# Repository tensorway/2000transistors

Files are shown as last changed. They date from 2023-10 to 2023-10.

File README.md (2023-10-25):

# 2000 MOSFET processor

The project is made in Kicad. If you want to learn more about it visit [howcpuworks.com](howcpuworks.com).

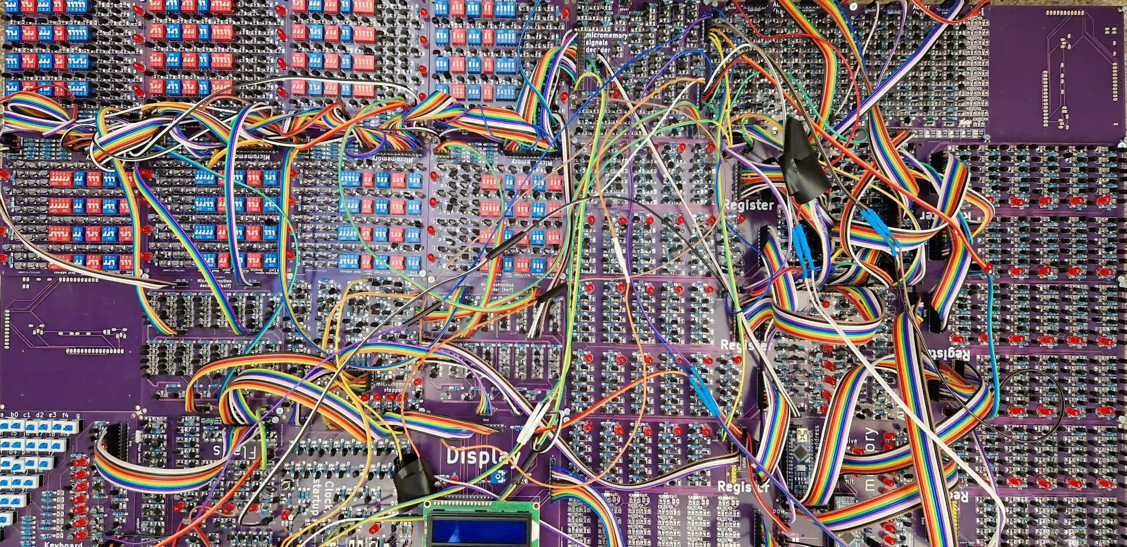
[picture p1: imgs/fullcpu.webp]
Full cpu AnVIL Portal Image!

Hello world AnVIL Portal Image!

## Conventions
- all transistors on a board point into the same direction (or 2 perpendicular ones if needed)
- all leds point into the same direction
- 1k resistors are labeled with white rectangle, 1M with empty one (only violation is in the Clock board and two voltage divider resistors in LCD board)
- "*" means high significance bits
- "+" means positive 5V

## Tips
- you dont need to use extra usb for the power, powering through arduino is enough
- Adder is made out of 2 smaller 6 bit adders, this means that you do not have to solder one bit (6+6=12 != 11)
- instruction register needs only 5bits which means you do not have to solder upper 6 bits (all registers are the same board to lower costs)
- when soldering
  - first put resistors
  - than transistors from the top left (top right if left handed)
  - leds and pin headers last

## Important
- to lower costs all registers have the same board, but TMP and IR registers do not have input and output connected to the bus, this means you have to connect it on other registers
- You need to find the voltage that works for your LCD contrast and put those resistors

## Components
- 2N7000 MOSFETs
- BC547 (BJT) only 4 for the astable
- 1000 ohm registers for leds
- 1M ohm for logic

## Bugs

While I could fix the bugs I do not want to check is everything working again because I would need to solder things again. This is why I list them, so you can either fix them yourselves before or after soldering (I did after).
Some bugs are just layout bugs, which means you need to be aware of them but not necessarily fix them.

Micromemory:
- shuffled by row led, select and switches - layout bug
- 0th line not connected to rest

Micromemory stepper:
- shuffeled LED state order - layout bug
- add delay from clock to it (for example RC)
   
Keyboard
- same signals for simetrical (with respect to keyboard diagonal) switches
  - effectively half the number of switches
- 1 bit not connected
  
Flags
- second to last carry and last carry labels mixed - layout bug
- flags selector selects 0 always

Clock
- manual clock does not have a debouncer

ALU
- add OR between ALU decoded ops and give Adder the output

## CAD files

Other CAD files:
src/kicad-footprints-master/Sources/Inductor_SMD/L_Coilcraft_LPS5030.FCStd
src/kicad-footprints-master/Sources/Package_LGA/Infineon_PG-LLGA-5-1.FCStd
src/kicad-footprints-master/Sources/Package_SON/X2SON-4_1x1mm_P0.65mm.fcstd
src/kicad-footprints-master/Sources/Package_TO_SOT_THT/sod-70.fcstd
src/kicad-footprints-master/Sources/Inductor_SMD/L_Wuerth_WE-TPC-3816.FCStd
src/kicad-footprints-master/Sources/Package_SON/X2SON-5_0.8x0.8mm_P0.48mm.fcstd
src/kicad-footprints-master/Sources/Package_TO_SOT_THT/sod-70_P5.08mm.fcstd

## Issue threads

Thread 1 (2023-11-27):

quick question

Dumnersm580, 2023-11-27:
what pcb's do i need to start this build?

Dumnersm580, 2023-11-27:
If possible could you provide a good photo of the adder? and i am guessing the ressistors needed for this board are the 1 mega ohm

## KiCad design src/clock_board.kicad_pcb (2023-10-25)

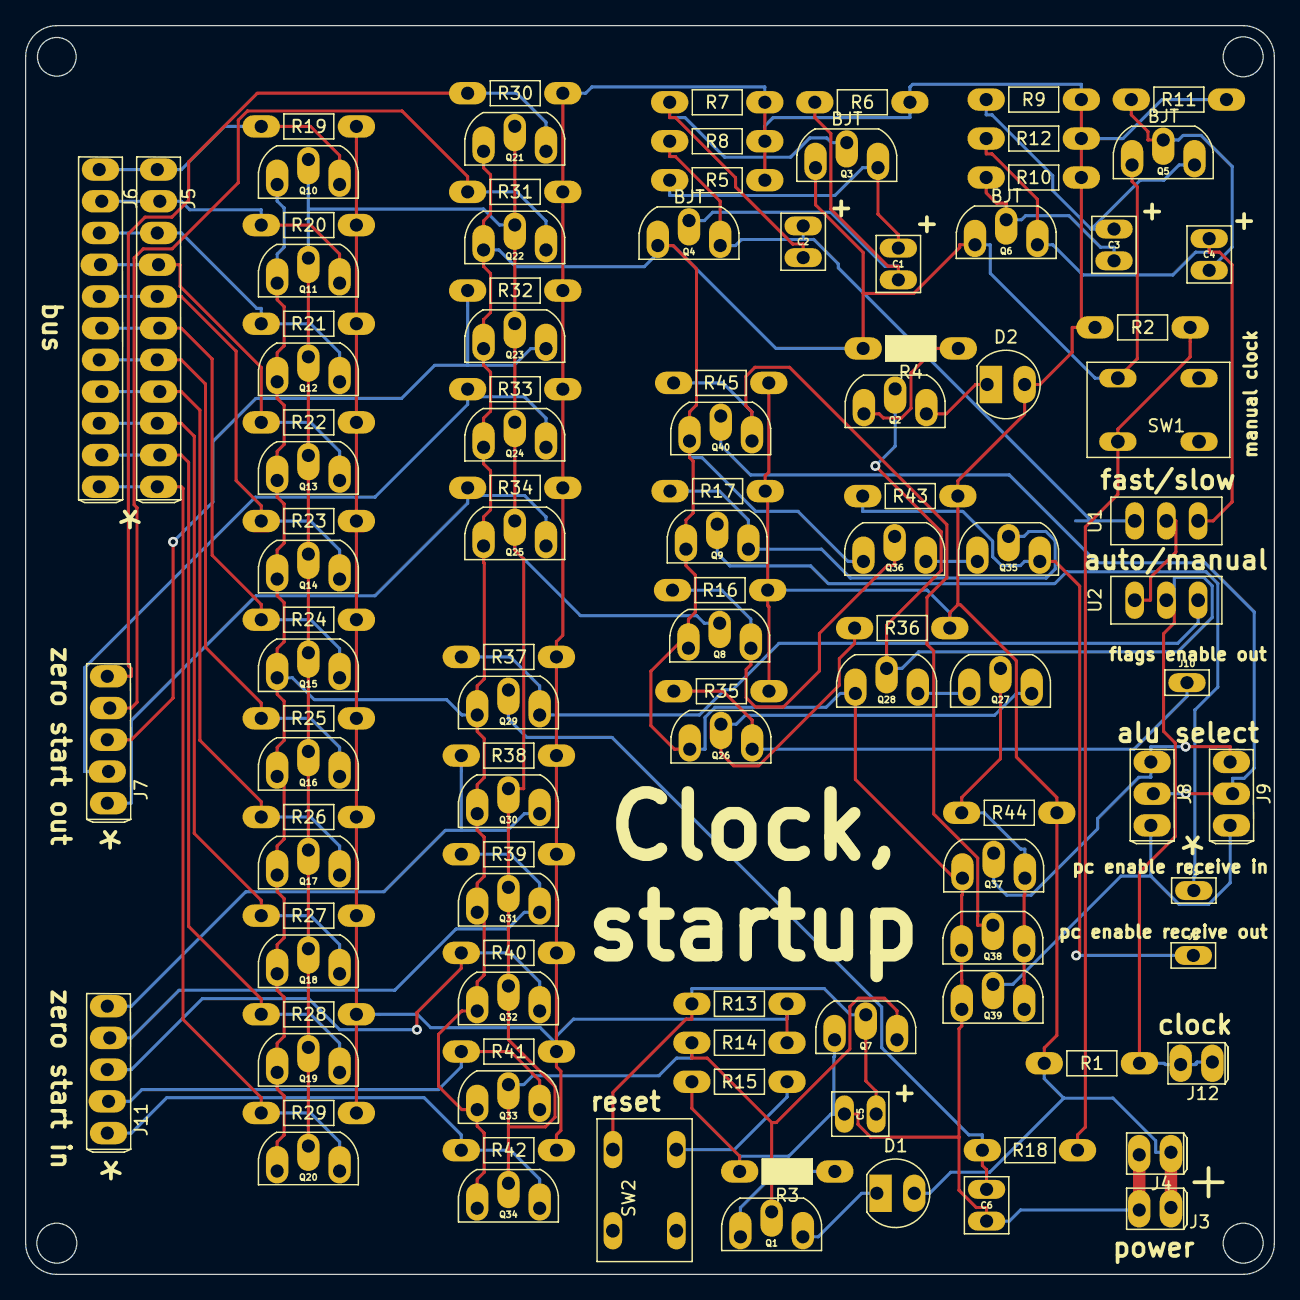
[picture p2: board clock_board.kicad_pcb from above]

Board: 2 copper layers, 100.0 x 100.0 mm, 109 parts (0 on the bottom side), 56 nets.

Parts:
C1, C2, C3, C4: CP; capacitor
C5, C6: C; capacitor
D1, D2: LED; led_5mm_tight
J1, J2: Conn_01x01_Male; 1pin
J3, J4, J12: Conn_01x02_Male; 2pin_tight
J5, J6: Conn_01x11_Male; 11pin_tight
J7, J11: Conn_01x05_Male; 5pin_tight
J8, J9: alu_sel; 3pin_tight
J10: flags_enable_out; 1pin
Q1, Q2, Q7, Q8, Q9, Q10, Q11, Q12, Q13, Q14, Q15, Q16, Q17, Q18, Q19, Q20, Q21, Q22, Q23, Q24, Q25, Q26, Q27, Q28, Q29, Q30, Q31, Q32, Q33, Q34, Q35, Q36, Q37, Q38, Q39, Q40: 2N7000; 2n7000_tight
Q3, Q4, Q5, Q6: 2N2219; bjt
R1, R2, R5, R6, R7, R8, R9, R10, R11, R12, R13, R14, R15, R16, R17, R18, R19, R20, R21, R22, R23, R24, R25, R26, R27, R28, R29, R30, R31, R32, R33, R34, R35, R36, R37, R38, R39, R40, R41, R42, R43, R44, R45: R; resistor_tight
R3, R4: R; resistor_led_tight
SW1, SW2: SW_Push_Dual; push_button
U1, U2: slide_switch

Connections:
+5V: D1.2, D2.2, J3.1, J4.1, R1.1, R2.1, R5.1, R6.1, R7.1, R8.1, R9.1, R10.1, R11.1, R12.1, R13.1, R14.1, R16.1, R17.1, R19.1, R20.1, R21.1, R22.1, R23.1, R24.1, R25.1, R26.1, R27.1, R28.1, R29.1, R30.1, R31.1, R32.1, R33.1, R34.1, R35.1, R36.1, R37.1, R38.1, R39.1, R40.1, R41.1, R42.1, R43.1, R44.1, R45.1
/Sheet63E28E4F/a: J5.11, J6.11, Q20.3, R29.2
/Sheet63E28E4F/ain: Q1.2, Q7.3, Q8.2, Q10.2, Q11.2, Q12.2, Q13.2, Q14.2, Q15.2, Q16.2, Q17.2, Q18.2, Q19.2, Q20.2, Q21.2, Q22.2, Q23.2, Q24.2, Q25.2, Q30.2, Q31.2, Q32.2, Q33.2, Q34.2, R14.2
/Sheet63E28E4F/b: J5.10, J6.10, Q19.3, R28.2
/Sheet63E28E4F/c: J5.9, J6.9, Q18.3, R27.2
/Sheet63E28E4F/d: J5.8, J6.8, Q17.3, R26.2
/Sheet63E28E4F/e: J5.7, J6.7, Q16.3, R25.2
/Sheet63E28E4F/f: J5.6, J6.6, Q15.3, R24.2
/Sheet63E28E4F/g: J5.5, J6.5, Q14.3, R23.2
/Sheet63E28E4F/h: J5.4, J6.4, Q13.3, R22.2
/Sheet63E28E4F/i: J5.3, J6.3, Q12.3, R21.2
/Sheet63E28E4F/j: J5.2, J6.2, Q11.3, R20.2
/Sheet63E28E4F/k: J5.1, J6.1, Q10.3, R19.2
/Sheet63E92C8A/a: J7.1, Q21.3, R30.2
/Sheet63E92C8A/b: J7.2, Q22.3, R31.2
/Sheet63E92C8A/c: J7.3, Q23.3, R32.2
/Sheet63E92C8A/d: J7.4, Q24.3, R33.2
/Sheet63E92C8A/e: J7.5, Q25.3, R34.2
/Sheet63F3BCE0/a: J8.1, J9.1, Q37.2
/Sheet63F3BCE0/b: Q38.2, Q40.3, R45.2
/Sheet63F3BCE0/c: J8.3, J9.3, Q39.2
/Sheet63F170A3/in: R2.2, R18.1, SW1.2
/fast_clck/out: C2.1, Q4.3, R8.2, U1.a
/sheet63E014FB/a: Q27.2, Q37.3, Q38.3, Q39.3, R44.2
/sheet63E014FB/b: J12.1, J12.2, Q2.2, Q28.2, R1.2, U2.common
/sheet63E014FC/in: J8.2, J9.2, Q40.2
/sheet63E741C0/a: Q9.3, Q35.2, R17.2
/sheet63E741C0/b: Q8.3, Q36.2, R16.2
/sheet63E741C0/out: J2.1, Q35.3, R43.2
/sheet63E741C1/in: J1.1, Q9.2
/sheet63E4453A/a: J11.1, Q30.3, R38.2
/sheet63E4453A/b: J11.2, Q31.3, R39.2
/sheet63E4453A/c: J11.3, Q32.3, R40.2
/sheet63E4453A/d: J11.4, Q33.3, R41.2
/sheet63E4453A/e: J11.5, Q34.3, R42.2
/sheet63F0C454/in: Q26.2, Q27.3, R36.2
/sheet63F0C454/out: J10.1, Q26.3, R35.2
/sheet63F5D8BA/in: C6.1, Q29.2, R18.2
/sheet63F5D8BA/out: Q29.3, R37.2, U2.b
/slow_clck/out: C4.1, Q6.3, R12.2, U1.b
GND: C5.2, C6.2, J3.2, J4.2, Q3.1, Q4.1, Q5.1, Q6.1, Q7.1, Q8.1, Q9.1, Q10.1, Q11.1, Q12.1, Q13.1, Q14.1, Q15.1, Q16.1, Q17.1, Q18.1, Q19.1, Q20.1, Q21.1, Q22.1, Q23.1, Q24.1, Q25.1, Q26.1, Q28.1, Q29.1, Q30.1, Q31.1, Q32.1, Q33.1, Q34.1, Q36.1, Q37.1, Q38.1, Q39.1, Q40.1, R3.2, R4.2, R15.2, SW1.1
unnamed: C1.1, Q3.3, R5.2
unnamed: C1.2, Q4.2, R6.2
unnamed: C2.2, Q3.2, R7.2
unnamed: C3.1, Q5.3, R9.2
unnamed: C3.2, Q6.2, R10.2
unnamed: C4.2, Q5.2, R11.2
unnamed: C5.1, Q7.2, R13.2, SW2.2
unnamed: D1.1, Q1.3
unnamed: D2.1, Q2.3
unnamed: Q1.1, R3.1
unnamed: Q2.1, R4.1
unnamed: Q27.1, Q28.3
unnamed: Q35.1, Q36.3
unnamed: R15.1, SW2.1
unnamed: U1.common, U2.a

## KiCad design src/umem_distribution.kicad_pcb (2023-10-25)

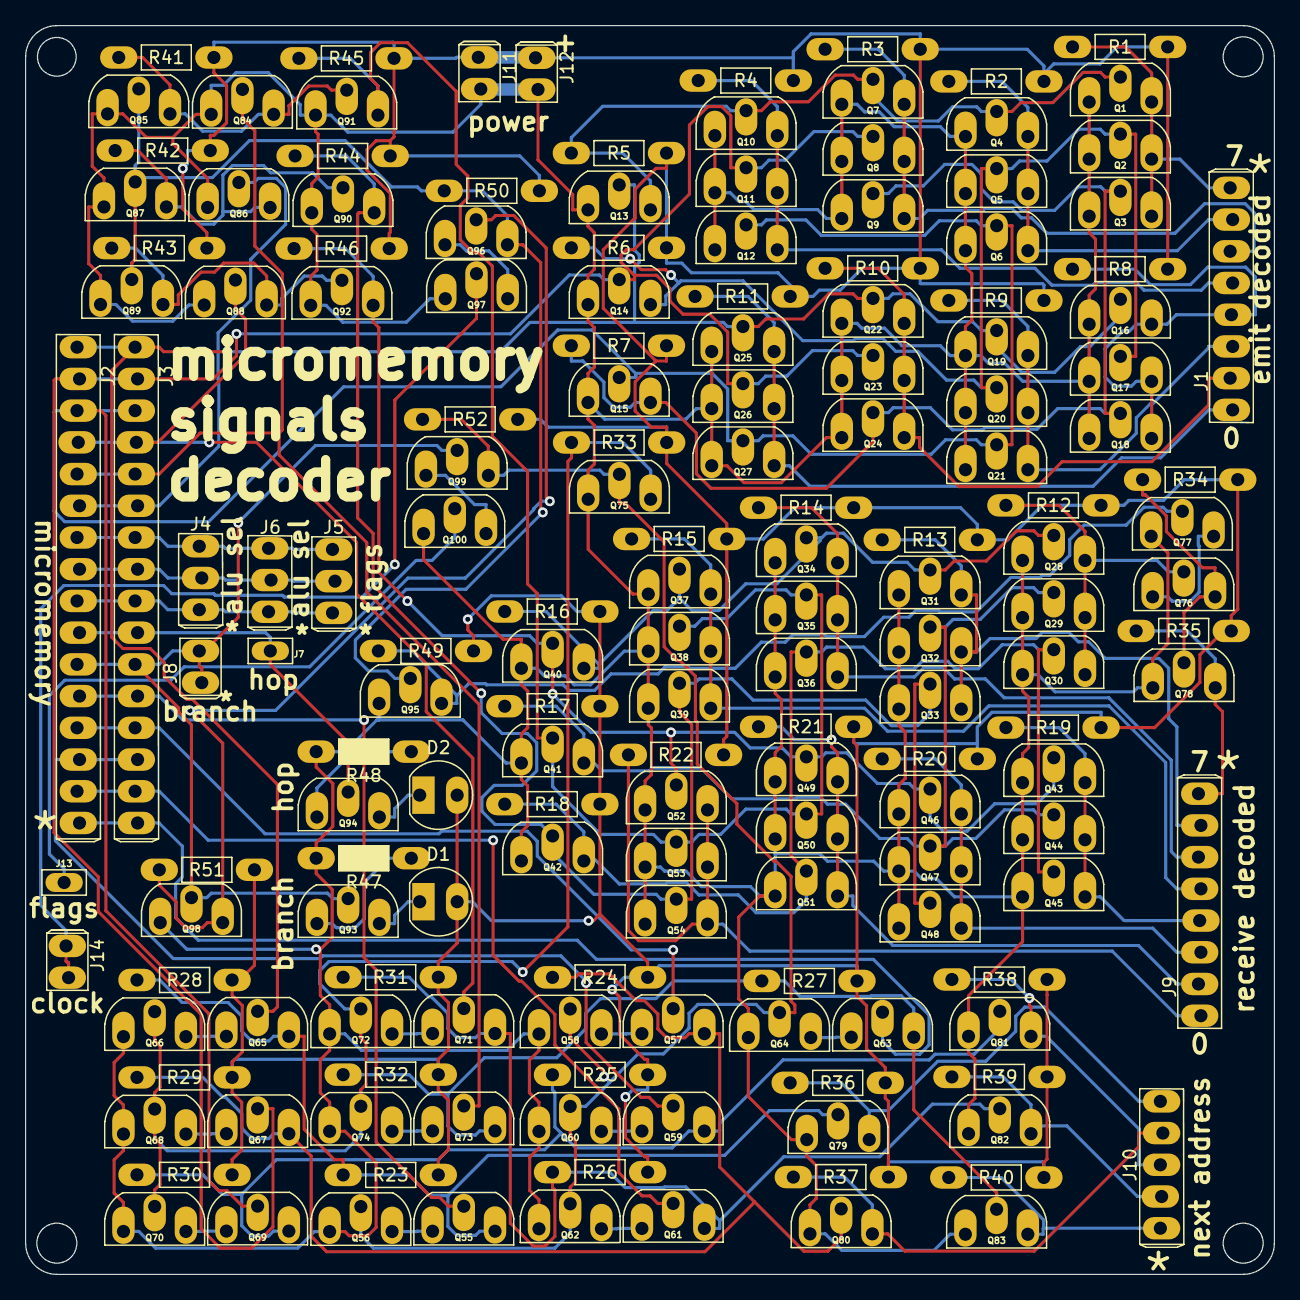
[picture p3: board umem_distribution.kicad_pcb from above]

Board: 2 copper layers, 100.0 x 100.0 mm, 168 parts (0 on the bottom side), 82 nets.

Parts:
D1, D2: LED; led_5mm_tight
J1: emit_signals; 8pin_tight
J2, J3: Conn_01x16_Male; 16pin_tight
J4: alu_sel; 3pin_tight
J5: flags; 3pin_tight
J6: alu sel; 3pin_tight
J7: hop; 1pin
J8: branch; 2pin_tight
J9: receive_signals; 8pin_tight
J10: Conn_01x05_Male; 5pin_tight
J11, J12: Conn_01x02_Male; 2pin_tight
J13: flags; 1pin
J14: clck; 2pin_tight
Q1, Q2, Q3, Q4, Q5, Q6, Q7, Q8, Q9, Q10, Q11, Q12, Q13, Q14, Q15, Q16, Q17, Q18, Q19, Q20, Q21, Q22, Q23, Q24, Q25, Q26, Q27, Q28, Q29, Q30, Q31, Q32, Q33, Q34, Q35, Q36, Q37, Q38, Q39, Q40, Q41, Q42, Q43, Q44, Q45, Q46, Q47, Q48, Q49, Q50, Q51, Q52, Q53, Q54, Q55, Q56, Q57, Q58, Q59, Q60, Q61, Q62, Q63, Q64, Q65, Q66, Q67, Q68, Q69, Q70, Q71, Q72, Q73, Q74, Q75, Q76, Q77, Q78, Q79, Q80, Q81, Q82, Q83, Q84, Q85, Q86, Q87, Q88, Q89, Q90, Q91, Q92, Q93, Q94, Q95, Q96, Q97, Q98, Q99, Q100: 2N7000; 2n7000_tight
R1, R2, R3, R4, R5, R6, R7, R8, R9, R10, R11, R12, R13, R14, R15, R16, R17, R18, R19, R20, R21, R22, R23, R24, R25, R26, R27, R28, R29, R30, R31, R32, R33, R34, R35, R36, R37, R38, R39, R40, R41, R42, R43, R44, R45, R46, R49, R50, R51, R52: R; resistor_tight
R47, R48: R; resistor_led_tight

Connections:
+5V: D1.2, D2.2, J11.1, J12.1, R1.1, R2.1, R3.1, R4.1, R5.1, R6.1, R7.1, R8.1, R9.1, R10.1, R11.1, R12.1, R13.1, R14.1, R15.1, R16.1, R17.1, R18.1, R19.1, R20.1, R21.1, R22.1, R23.1, R24.1, R25.1, R26.1, R27.1, R28.1, R29.1, R30.1, R31.1, R32.1, R33.1, R34.1, R35.1, R36.1, R37.1, R38.1, R39.1, R40.1, R41.1, R42.1, R43.1, R44.1, R45.1, R46.1, R49.1, R50.1, R51.1, R52.1
/Sheet63E6B315/a: Q40.2, Q43.2, Q46.2, Q49.2, Q52.2, Q92.3, R46.2
/Sheet63E6B315/b: Q35.2, Q38.2, Q41.2, Q50.2, Q53.2, Q91.3, R45.2
/Sheet63E6B315/c: Q33.2, Q39.2, Q42.2, Q48.2, Q54.2, Q90.3, R44.2
/Sheet63E6B315/cin: J2.6, J3.6, Q86.2
/Sheet63E6B315/enable: Q85.2, Q87.2, Q89.2, Q95.2, Q96.3, R50.2
/Sheet63E6B315/sheet63E6BA43/in: Q86.3, Q87.3, Q90.2, R42.2
/Sheet63E6B315/sheet63E6BA44/in: Q84.3, Q85.3, Q91.2, R41.2
/Sheet63E6B315/sheet63E6BA45/in: Q88.3, Q89.3, Q92.2, R43.2
/Sheet63E20833/a: J10.1, Q79.3, R36.2
/Sheet63E20833/ain: Q55.3, Q65.3, Q79.2, R23.2, R28.2
/Sheet63E20833/b: J10.2, Q80.3, R37.2
/Sheet63E20833/bin: Q57.3, Q67.3, Q80.2, R24.2, R29.2
/Sheet63E20833/c: J10.3, Q81.3, R38.2
/Sheet63E20833/cin: Q59.3, Q69.3, Q81.2, R25.2, R30.2
/Sheet63E20833/d: J10.4, Q82.3, R39.2
/Sheet63E20833/din: Q61.3, Q71.3, Q82.2, R26.2, R31.2
/Sheet63E20833/e: J10.5, Q83.3, R40.2
/Sheet63E20833/ein: Q63.3, Q73.3, Q83.2, R27.2, R32.2
/Sheet6491BA02/a: J2.11, J3.11, J8.1, J8.2, Q93.2, Q98.2, Q99.2
/Sheet6491BA02/b: J13.1, Q100.2
/Sheet6486733A/a: Q96.2, Q98.3, R51.2
/Sheet6486733A/b: J14.1, J14.2, Q97.2
/emit/Sheet63BAB2B1/a: Q1.2, Q4.2, Q7.2, Q10.2, Q13.3, R5.2
/emit/Sheet63BAB2B1/b: Q2.2, Q5.2, Q14.3, Q17.2, Q20.2, R6.2
/emit/Sheet63BAB2B1/c: Q3.2, Q9.2, Q15.3, Q18.2, Q24.2, R7.2
/emit/a: J1.1, Q25.3, Q26.3, Q27.3, R11.2
/emit/b: J1.2, Q22.3, Q23.3, Q24.3, R10.2
/emit/c: J1.3, Q19.3, Q20.3, Q21.3, R9.2
/emit/d: J1.4, Q16.3, Q17.3, Q18.3, R8.2
/emit/e: J1.5, Q10.3, Q11.3, Q12.3, R4.2
/emit/f: J1.6, Q7.3, Q8.3, Q9.3, R3.2
/emit/g: J1.7, Q4.3, Q5.3, Q6.3, R2.2
/emit/h: J1.8, Q1.3, Q2.3, Q3.3, R1.2
/hop/in: J2.10, J3.10, J7.1, Q94.2
/receive/Sheet63BAB2B1/a: Q28.2, Q31.2, Q34.2, Q37.2, Q40.3, R16.2
/receive/Sheet63BAB2B1/b: Q29.2, Q32.2, Q41.3, Q44.2, Q47.2, R17.2
/receive/Sheet63BAB2B1/c: Q30.2, Q36.2, Q42.3, Q45.2, Q51.2, R18.2
/receive/a: J9.1, Q52.3, Q53.3, Q54.3, R22.2
/receive/b: J9.2, Q49.3, Q50.3, Q51.3, R21.2
/receive/c: J9.3, Q46.3, Q47.3, Q48.3, R20.2
/receive/d: J9.4, Q43.3, Q44.3, Q45.3, R19.2
/receive/e: J9.5, Q37.3, Q38.3, Q39.3, R15.2
/receive/f: J9.6, Q34.3, Q35.3, Q36.3, R14.2
/receive/g: J9.7, Q31.3, Q32.3, Q33.3, R13.2
/sheet63E5B14C/a: J2.13, J3.13, Q57.2
/sheet63E5C954/a: J2.14, J3.14, Q59.2
/sheet63E5E118/a: J2.15, J3.15, Q61.2
/sheet63E5F8EC/a: J2.16, J3.16, Q63.2
/sheet63E6165A/a: J2.1, J3.1, Q13.2, Q16.2, Q19.2, Q22.2, Q25.2, Q65.2
/sheet63E6165A/b: Q66.2, Q68.2, Q70.2, Q72.2, Q74.2, Q75.3, R33.2
/sheet63E6165B/a: J2.2, J3.2, Q8.2, Q11.2, Q14.2, Q23.2, Q26.2, Q67.2
/sheet63E6165C/a: J2.3, J3.3, Q6.2, Q12.2, Q15.2, Q21.2, Q27.2, Q69.2
/sheet63E6165D/a: J2.4, J3.4, Q71.2, Q88.2
/sheet63E6165E/a: J2.5, J3.5, Q73.2, Q84.2
/sheet63E59739/a: J2.12, J3.12, Q55.2
/sheet63E59739/b: Q56.2, Q58.2, Q60.2, Q62.2, Q64.2, Q75.2, Q99.3, R52.2
/sheet640275C6/a: Q28.3, Q29.3, Q30.3, Q76.2, R12.2
/sheet640275C6/b: Q77.2, Q95.3, R49.2
/sheet640275C7/in: Q76.3, Q78.2, R34.2
/sheet640275C7/out: J9.8, Q78.3, R35.2
GND: J11.2, J12.2, Q1.1, Q2.1, Q3.1, Q4.1, Q5.1, Q6.1, Q7.1, Q8.1, Q9.1, Q10.1, Q11.1, Q12.1, Q13.1, Q14.1, Q15.1, Q16.1, Q17.1, Q18.1, Q19.1, Q20.1, Q21.1, Q22.1, Q23.1, Q24.1, Q25.1, Q26.1, Q27.1, Q28.1, Q29.1, Q30.1, Q31.1, Q32.1, Q33.1, Q34.1, Q35.1, Q36.1, Q37.1, Q38.1, Q39.1, Q40.1, Q41.1, Q42.1, Q43.1, Q44.1, Q45.1, Q46.1, Q47.1, Q48.1, Q49.1, Q50.1, Q51.1, Q52.1, Q53.1, Q54.1, Q56.1, Q58.1, Q60.1, Q62.1, Q64.1, Q66.1, Q68.1, Q70.1, Q72.1, Q74.1, Q75.1, Q77.1, Q78.1, Q79.1, Q80.1, Q81.1, Q82.1, Q83.1, Q84.1, Q85.1, Q86.1, Q87.1, Q88.1, Q89.1, Q90.1, Q91.1, Q92.1, Q95.1, Q97.1, Q98.1, Q100.1, R47.2, R48.2
unnamed: D1.1, Q93.3
unnamed: D2.1, Q94.3
unnamed: J2.7, J3.7, J4.1, J5.1, J6.1
unnamed: J2.8, J3.8, J4.2, J5.2, J6.2
unnamed: J2.9, J3.9, J4.3, J5.3, J6.3
unnamed: Q55.1, Q56.3
unnamed: Q57.1, Q58.3
unnamed: Q59.1, Q60.3
unnamed: Q61.1, Q62.3
unnamed: Q63.1, Q64.3
unnamed: Q65.1, Q66.3
unnamed: Q67.1, Q68.3
unnamed: Q69.1, Q70.3
unnamed: Q71.1, Q72.3
unnamed: Q73.1, Q74.3
unnamed: Q76.1, Q77.3
unnamed: Q93.1, R47.1
unnamed: Q94.1, R48.1
unnamed: Q96.1, Q97.3
unnamed: Q99.1, Q100.3

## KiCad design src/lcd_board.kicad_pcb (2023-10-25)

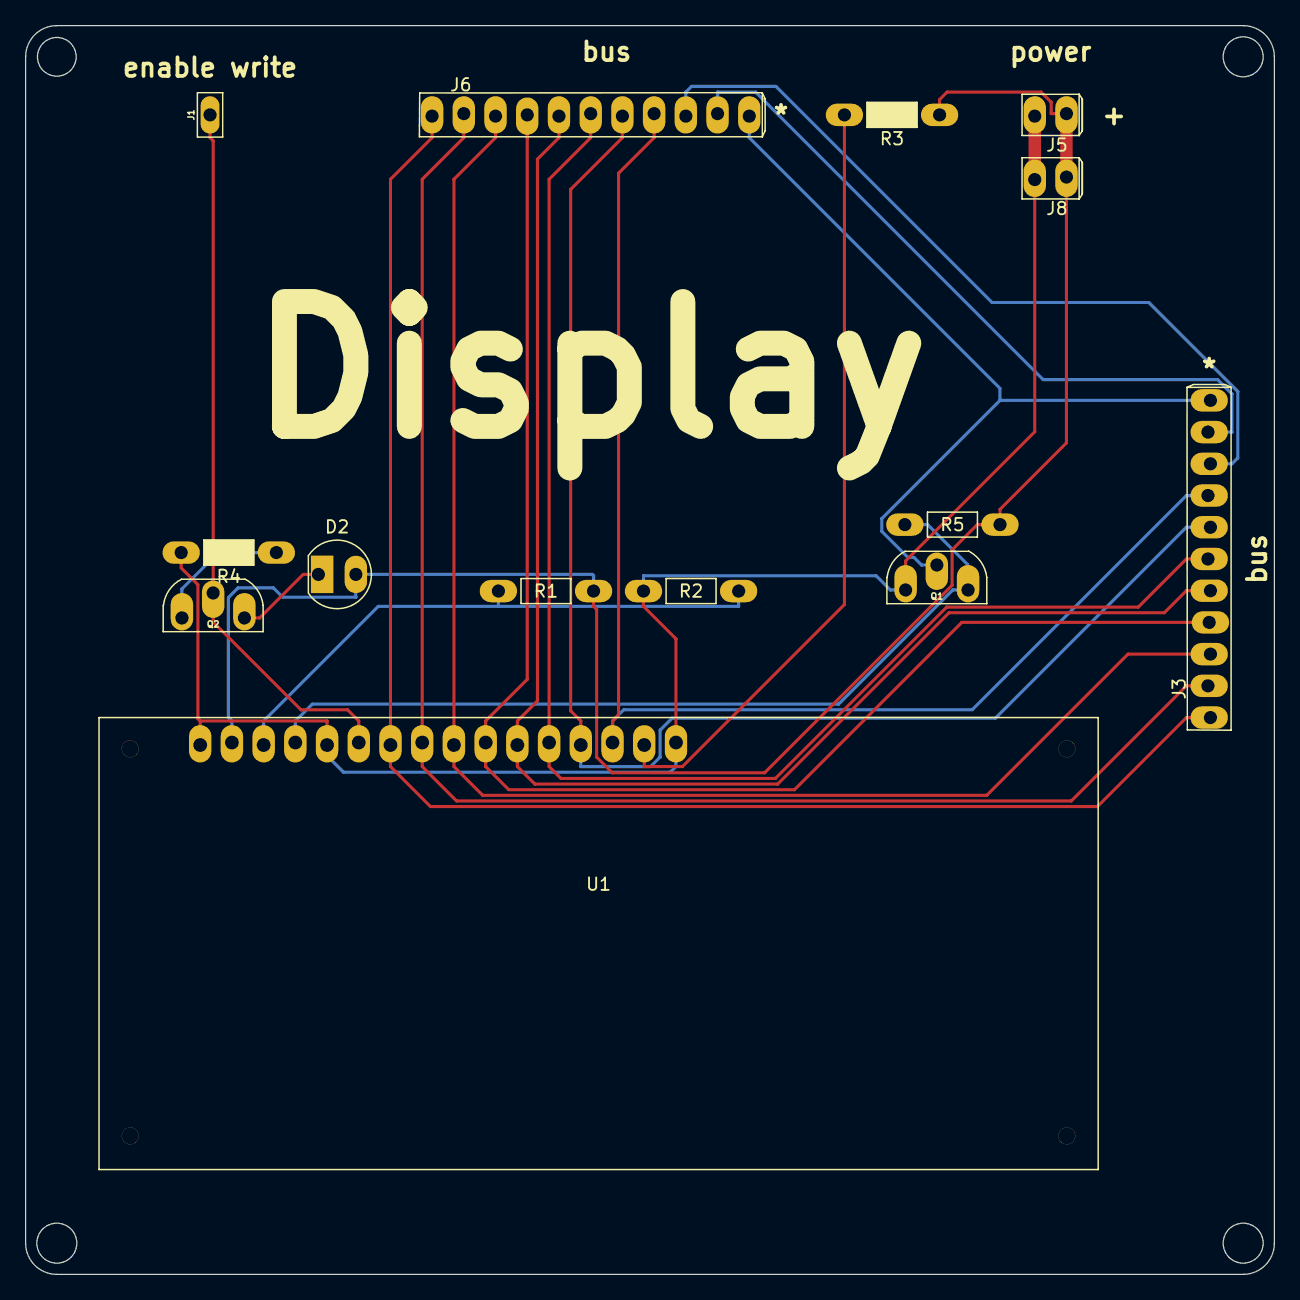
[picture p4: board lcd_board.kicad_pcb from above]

Board: 2 copper layers, 100.0 x 100.0 mm, 14 parts (0 on the bottom side), 19 nets.

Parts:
D2: LED; led_5mm_tight
J1: Conn_01x01_Male; 1pin
J3, J6: Conn_01x11_Male; 11pin_tight
J5, J8: Conn_01x02_Male; 2pin_tight
Q1, Q2: 2N7000; 2n7000_tight
R1, R2, R5: R; resistor_tight
R3, R4: R; resistor_led_tight
U1: lcd_display

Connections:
+5V: D2.2, J5.1, J8.1, R1.1, R3.1, R5.1, U1.5v
/Sheet63DF1E83/in: J3.11, J6.11, Q1.2
/Sheet63DF1E83/out: Q1.3, R5.2, U1.register_select
/sheet63DE894A/in: J1.1, Q2.2, U1.enable
GND: J5.2, J8.2, Q1.1, R2.2, R4.2, U1.gnd, U1.led_negative, U1.read/write
unnamed: D2.1, Q2.3
unnamed: J3.1, J6.1, U1.d0
unnamed: J3.2, J6.2, U1.d1
unnamed: J3.3, J6.3, U1.d2
unnamed: J3.4, J6.4, U1.d3
unnamed: J3.5, J6.5, U1.d4
unnamed: J3.6, J6.6, U1.d5
unnamed: J3.7, J6.7, U1.d6
unnamed: J3.8, J6.8, U1.d7
unnamed: J3.9, J6.9
unnamed: J3.10, J6.10
unnamed: Q2.1, R4.1
unnamed: R1.2, R2.1, U1.contrast
unnamed: R3.2, U1.led_positive

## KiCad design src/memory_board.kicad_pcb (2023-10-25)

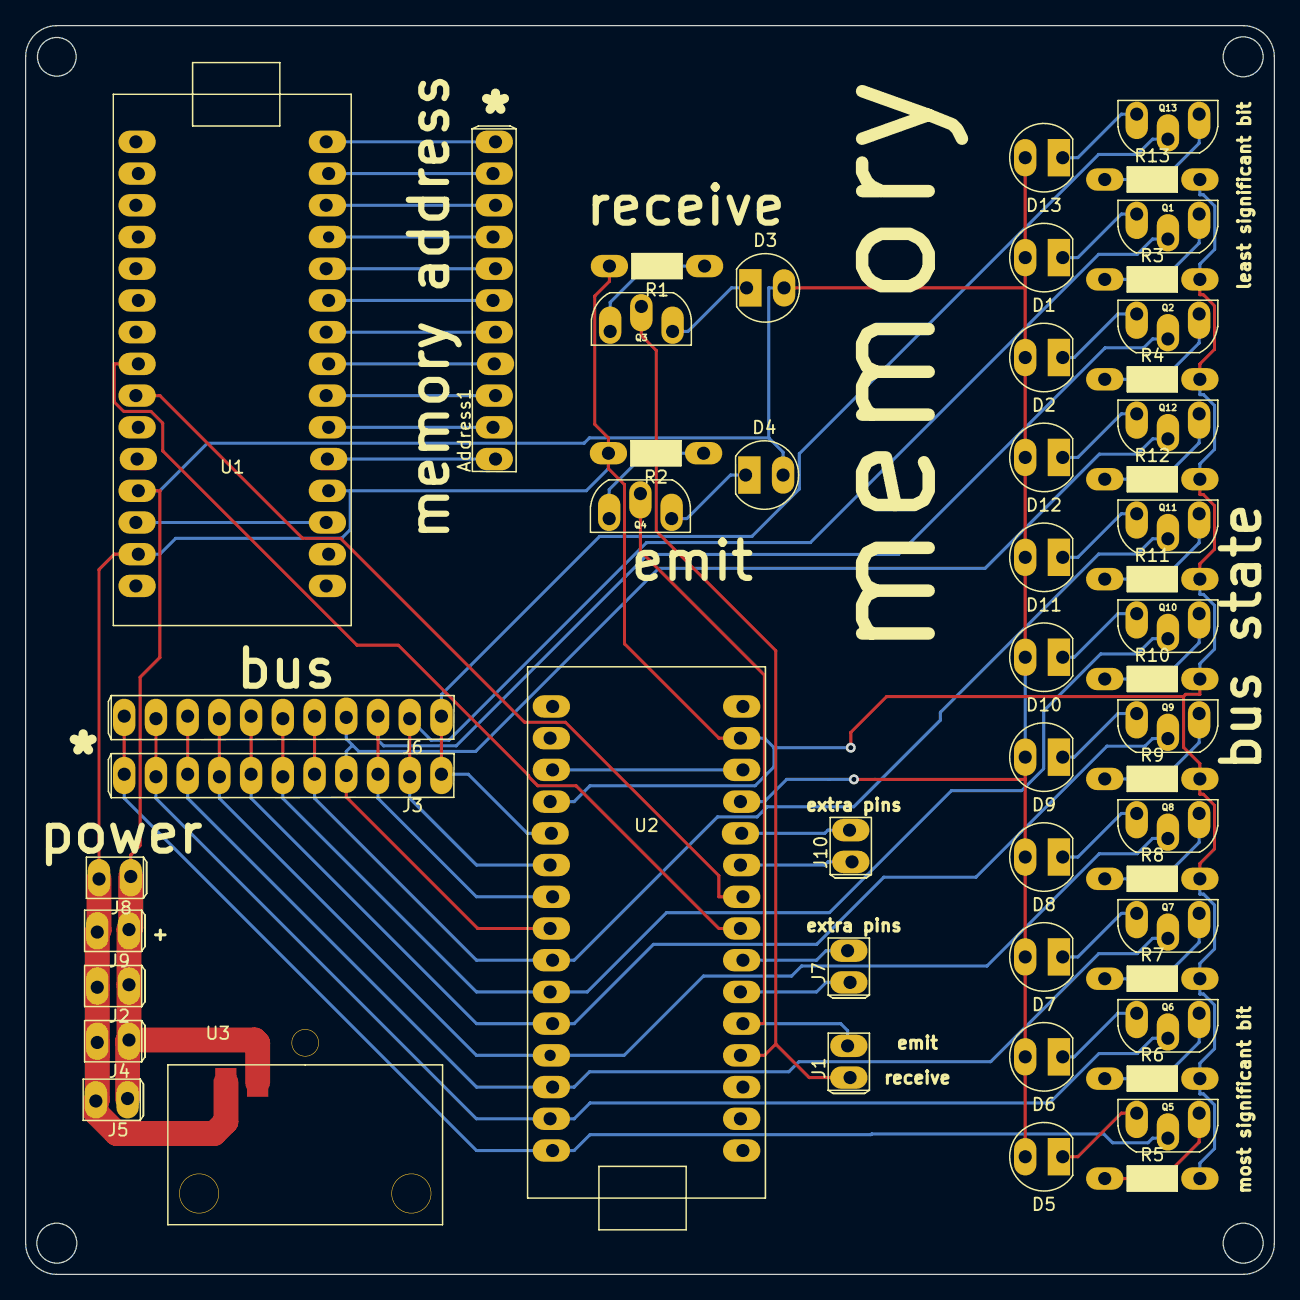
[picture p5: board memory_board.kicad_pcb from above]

Board: 2 copper layers, 100.0 x 100.0 mm, 53 parts (0 on the bottom side), 58 nets.

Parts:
Address1: Conn_01x11_Male; 11pin_tight
D1, D2, D3, D4, D5, D6, D7, D8, D9, D10, D11, D12, D13: LED; led_5mm_tight
J1, J2, J4, J5, J8, J9: Conn_01x02_Male; 2pin_tight
J3, J6: Conn_01x11_Male; 11pin_tight
J7: emergency_pins_1; 2pin_tight
J10: emergency_pins_2; 2pin_tight
Q1, Q2, Q3, Q4, Q5, Q6, Q7, Q8, Q9, Q10, Q11, Q12, Q13: 2N7000; 2n7000_tight
R1, R2, R3, R4, R5, R6, R7, R8, R9, R10, R11, R12, R13: R; resistor_led_tight
U1, U2: arduino_nano
U3: usb_c_power

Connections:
+5V: D1.2, D2.2, D3.2, D4.2, D5.2, D6.2, D7.2, D8.2, D9.2, D10.2, D11.2, D12.2, D13.2, J2.1, J4.1, J5.1, J8.1, J9.1, U1.5V, U2.5V, U3.gnd
/Sheet63DB05CB/in: J1.1, Q3.2, U2.a0
/sheet63DB2CAC/in: J1.2, Q4.2, U2.a1
/sheet63DBD05A/in: J3.11, J6.11, Q5.2, U2.d12
/sheet63DBD05B/in: J3.10, J6.10, Q6.2, U2.d11
/sheet63DC1151/in: J3.9, J6.9, Q7.2, U2.d10
/sheet63DC1152/in: J3.8, J6.8, Q8.2, U2.d9
/sheet63DCF52A/in: J3.7, J6.7, Q9.2, U2.d8
/sheet63DCF52B/in: J3.6, J6.6, Q10.2, U2.d7
/sheet63DCF52C/in: J3.5, J6.5, Q11.2, U2.d6
/sheet63DCF52D/in: J3.4, J6.4, Q12.2, U2.d5
/sheet63DE894A/in: J3.3, J6.3, Q2.2, U2.d4
/sheet63DE894B/in: J3.2, J6.2, Q1.2, U2.d3
/sheet63DE894C/in: J3.1, J6.1, Q13.2, U2.d2
GND: J2.2, J4.2, J5.2, J8.2, J9.2, R1.2, R2.2, R3.2, R4.2, R5.2, R6.2, R7.2, R8.2, R9.2, R10.2, R11.2, R12.2, R13.2, U1.GND, U2.GND, U3.5v
unnamed: Address1.1, U1.d2
unnamed: Address1.2, U1.d3
unnamed: Address1.3, U1.d4
unnamed: Address1.4, U1.d5
unnamed: Address1.5, U1.d6
unnamed: Address1.6, U1.d7
unnamed: Address1.7, U1.d8
unnamed: Address1.8, U1.d9
unnamed: Address1.9, U1.d10
unnamed: Address1.10, U1.d11
unnamed: Address1.11, U1.d12
unnamed: D1.1, Q1.3
unnamed: D2.1, Q2.3
unnamed: D3.1, Q3.3
unnamed: D4.1, Q4.3
unnamed: D5.1, Q5.3
unnamed: D6.1, Q6.3
unnamed: D7.1, Q7.3
unnamed: D8.1, Q8.3
unnamed: D9.1, Q9.3
unnamed: D10.1, Q10.3
unnamed: D11.1, Q11.3
unnamed: D12.1, Q12.3
unnamed: D13.1, Q13.3
unnamed: J7.1, U2.a2
unnamed: J7.2, U2.a3
unnamed: J10.1, U2.a6
unnamed: J10.2, U2.a7
unnamed: Q1.1, R3.1
unnamed: Q2.1, R4.1
unnamed: Q3.1, R1.1
unnamed: Q4.1, R2.1
unnamed: Q5.1, R5.1
unnamed: Q6.1, R6.1
unnamed: Q7.1, R7.1
unnamed: Q8.1, R8.1
unnamed: Q9.1, R9.1
unnamed: Q10.1, R10.1
unnamed: Q11.1, R11.1
unnamed: Q12.1, R12.1
unnamed: Q13.1, R13.1
unnamed: U1.SCL, U2.SCL
unnamed: U1.SDA, U2.SDA

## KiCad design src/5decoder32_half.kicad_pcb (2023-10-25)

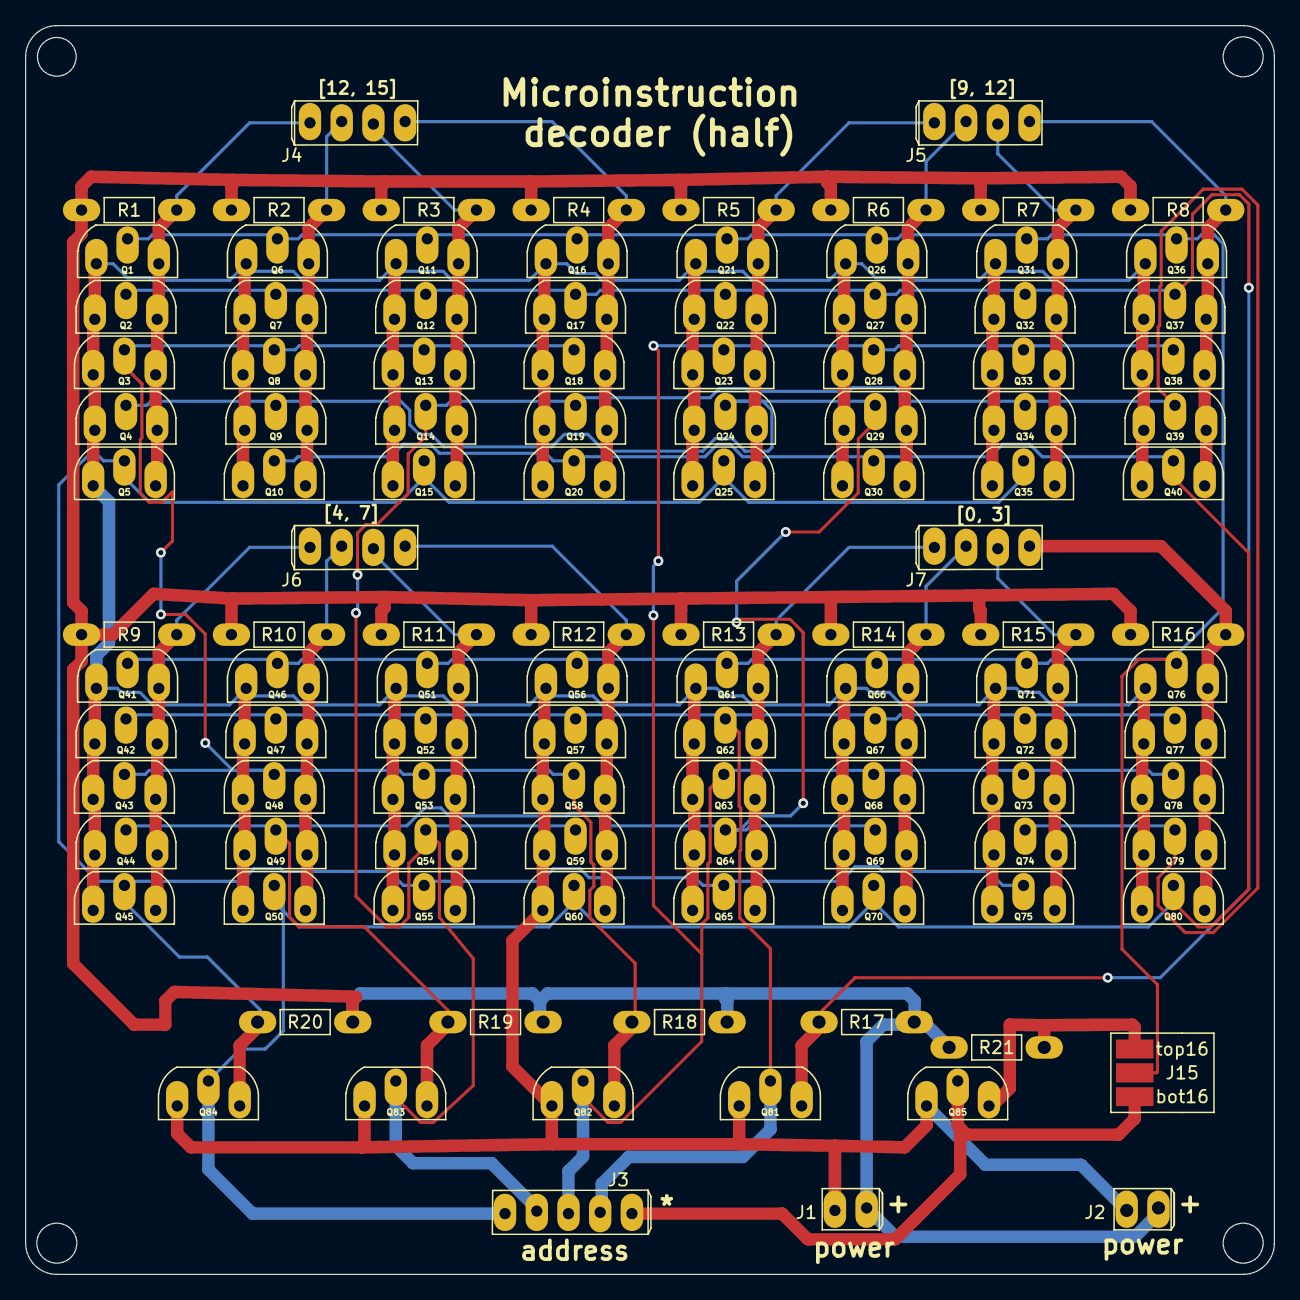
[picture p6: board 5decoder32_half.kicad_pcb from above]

Board: 2 copper layers, 100.0 x 100.0 mm, 114 parts (0 on the bottom side), 29 nets.

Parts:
J1, J2: Conn_01x02_Male; 2pin_tight
J3: Conn_01x05_Male; 5pin_tight
J4, J5, J6, J7: Conn_01x04_Male; 4pin_tight
J15: Conn_01x03_Male; 3hardware_selector
Q1, Q2, Q3, Q4, Q5, Q6, Q7, Q8, Q9, Q10, Q11, Q12, Q13, Q14, Q15, Q16, Q17, Q18, Q19, Q20, Q21, Q22, Q23, Q24, Q25, Q26, Q27, Q28, Q29, Q30, Q31, Q32, Q33, Q34, Q35, Q36, Q37, Q38, Q39, Q40, Q41, Q42, Q43, Q44, Q45, Q46, Q47, Q48, Q49, Q50, Q51, Q52, Q53, Q54, Q55, Q56, Q57, Q58, Q59, Q60, Q61, Q62, Q63, Q64, Q65, Q66, Q67, Q68, Q69, Q70, Q71, Q72, Q73, Q74, Q75, Q76, Q77, Q78, Q79, Q80, Q81, Q82, Q83, Q84, Q85: 2N7000; 2n7000_tight
R1, R2, R3, R4, R5, R6, R7, R8, R9, R10, R11, R12, R13, R14, R15, R16, R17, R18, R19, R20, R21: R; resistor_tight

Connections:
+5V: J1.1, J2.1, R1.1, R2.1, R3.1, R4.1, R5.1, R6.1, R7.1, R8.1, R9.1, R10.1, R11.1, R12.1, R13.1, R14.1, R15.1, R16.1, R17.1, R18.1, R19.1, R20.1, R21.1
/Sheet63BAD094/out: J4.4, Q1.3, Q2.3, Q3.3, Q4.3, Q5.3, R1.2
/Sheet63C0593F/a: J3.5, J15.1, Q85.2
/Sheet63C0593F/na: J15.3, Q85.3, R21.2
/asel: J15.2, Q1.2, Q6.2, Q11.2, Q16.2, Q21.2, Q26.2, Q31.2, Q36.2, Q41.2, Q46.2, Q51.2, Q56.2, Q61.2, Q66.2, Q71.2, Q76.2
/b: J3.4, Q42.2, Q47.2, Q52.2, Q57.2, Q62.2, Q67.2, Q72.2, Q77.2, Q81.2
/c: J3.3, Q23.2, Q28.2, Q33.2, Q38.2, Q63.2, Q68.2, Q73.2, Q78.2, Q82.2
/d: J3.2, Q14.2, Q19.2, Q34.2, Q39.2, Q54.2, Q59.2, Q74.2, Q79.2, Q83.2
/e: J3.1, Q10.2, Q20.2, Q30.2, Q40.2, Q50.2, Q60.2, Q70.2, Q80.2, Q84.2
/nb: Q2.2, Q7.2, Q12.2, Q17.2, Q22.2, Q27.2, Q32.2, Q37.2, Q81.3, R17.2
/nc: Q3.2, Q8.2, Q13.2, Q18.2, Q43.2, Q48.2, Q53.2, Q58.2, Q82.3, R18.2
/nd: Q4.2, Q9.2, Q24.2, Q29.2, Q44.2, Q49.2, Q64.2, Q69.2, Q83.3, R19.2
/ne: Q5.2, Q15.2, Q25.2, Q35.2, Q45.2, Q55.2, Q65.2, Q75.2, Q84.3, R20.2
/sheet63BC13F1/out: J4.3, Q6.3, Q7.3, Q8.3, Q9.3, Q10.3, R2.2
/sheet63BC40A0/out: J5.3, Q26.3, Q27.3, Q28.3, Q29.3, Q30.3, R6.2
/sheet63BC40A1/out: J5.2, Q31.3, Q32.3, Q33.3, Q34.3, Q35.3, R7.2
/sheet63BC40A2/out: J5.1, Q36.3, Q37.3, Q38.3, Q39.3, Q40.3, R8.2
/sheet63BC409F/out: J5.4, Q21.3, Q22.3, Q23.3, Q24.3, Q25.3, R5.2
/sheet63BC745C/out: J6.4, Q41.3, Q42.3, Q43.3, Q44.3, Q45.3, R9.2
/sheet63BC745D/out: J6.3, Q46.3, Q47.3, Q48.3, Q49.3, Q50.3, R10.2
/sheet63BC745E/out: J6.2, Q51.3, Q52.3, Q53.3, Q54.3, Q55.3, R11.2
/sheet63BC745F/out: J6.1, Q56.3, Q57.3, Q58.3, Q59.3, Q60.3, R12.2
/sheet63BC2018/out: J4.2, Q11.3, Q12.3, Q13.3, Q14.3, Q15.3, R3.2
/sheet63BC2019/out: J4.1, Q16.3, Q17.3, Q18.3, Q19.3, Q20.3, R4.2
/sheet63BC7460/out: J7.4, Q61.3, Q62.3, Q63.3, Q64.3, Q65.3, R13.2
/sheet63BC7461/out: J7.3, Q66.3, Q67.3, Q68.3, Q69.3, Q70.3, R14.2
/sheet63BC7462/out: J7.2, Q71.3, Q72.3, Q73.3, Q74.3, Q75.3, R15.2
/sheet63BC7463/out: J7.1, Q76.3, Q77.3, Q78.3, Q79.3, Q80.3, R16.2
GND: J1.2, J2.2, Q1.1, Q2.1, Q3.1, Q4.1, Q5.1, Q6.1, Q7.1, Q8.1, Q9.1, Q10.1, Q11.1, Q12.1, Q13.1, Q14.1, Q15.1, Q16.1, Q17.1, Q18.1, Q19.1, Q20.1, Q21.1, Q22.1, Q23.1, Q24.1, Q25.1, Q26.1, Q27.1, Q28.1, Q29.1, Q30.1, Q31.1, Q32.1, Q33.1, Q34.1, Q35.1, Q36.1, Q37.1, Q38.1, Q39.1, Q40.1, Q41.1, Q42.1, Q43.1, Q44.1, Q45.1, Q46.1, Q47.1, Q48.1, Q49.1, Q50.1, Q51.1, Q52.1, Q53.1, Q54.1, Q55.1, Q56.1, Q57.1, Q58.1, Q59.1, Q60.1, Q61.1, Q62.1, Q63.1, Q64.1, Q65.1, Q66.1, Q67.1, Q68.1, Q69.1, Q70.1, Q71.1, Q72.1, Q73.1, Q74.1, Q75.1, Q76.1, Q77.1, Q78.1, Q79.1, Q80.1, Q81.1, Q82.1, Q83.1, Q84.1, Q85.1

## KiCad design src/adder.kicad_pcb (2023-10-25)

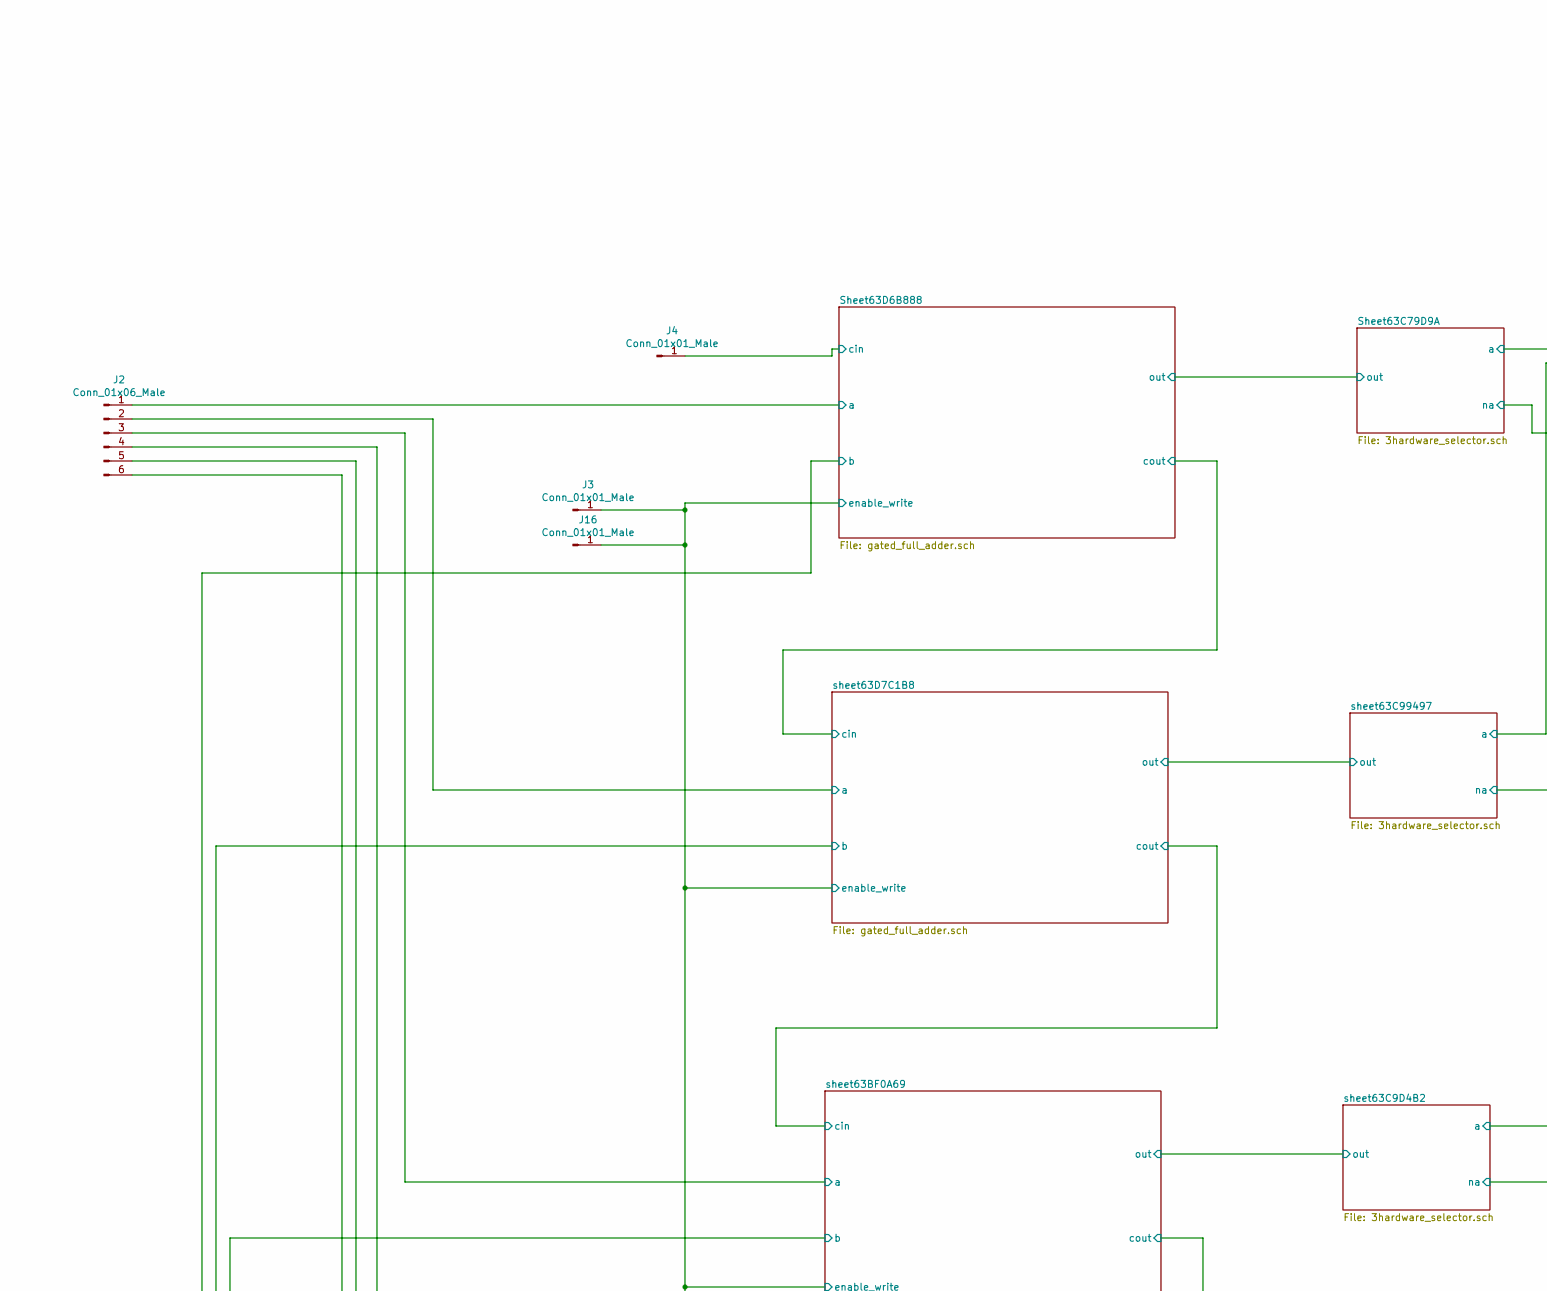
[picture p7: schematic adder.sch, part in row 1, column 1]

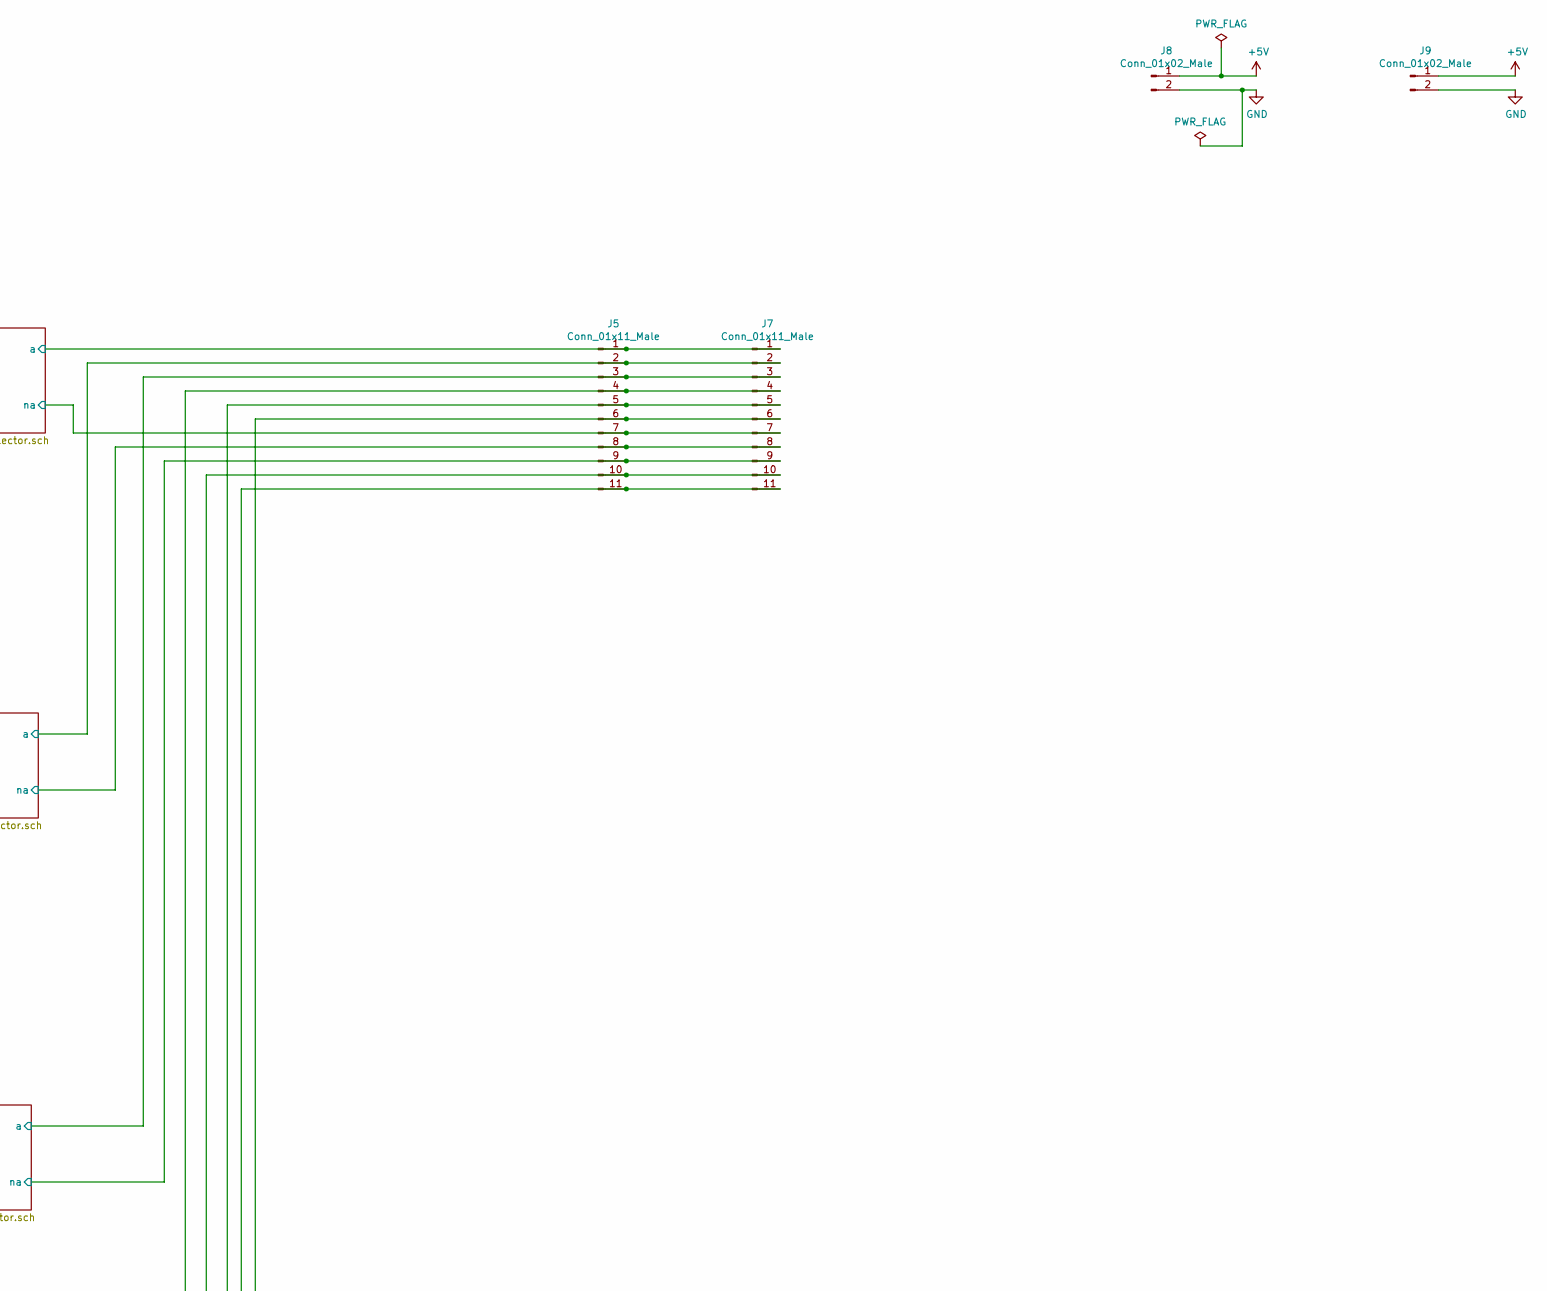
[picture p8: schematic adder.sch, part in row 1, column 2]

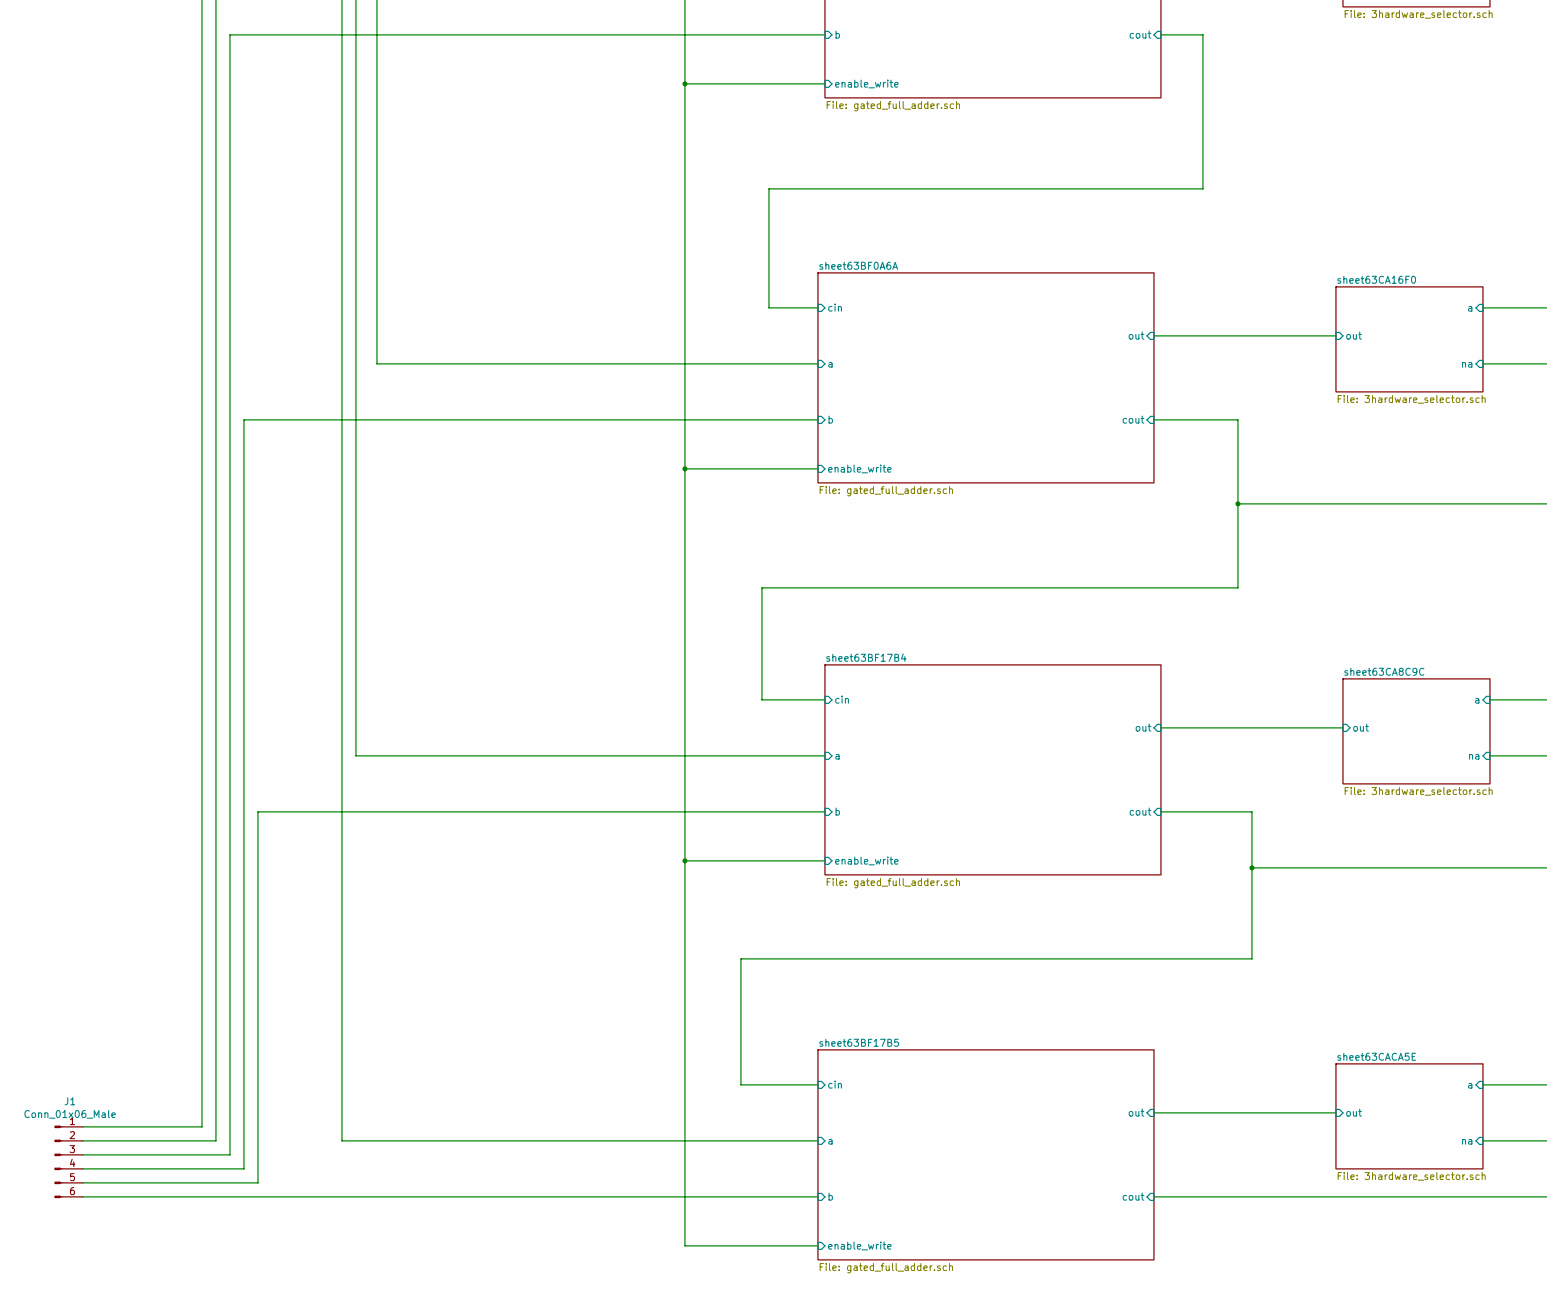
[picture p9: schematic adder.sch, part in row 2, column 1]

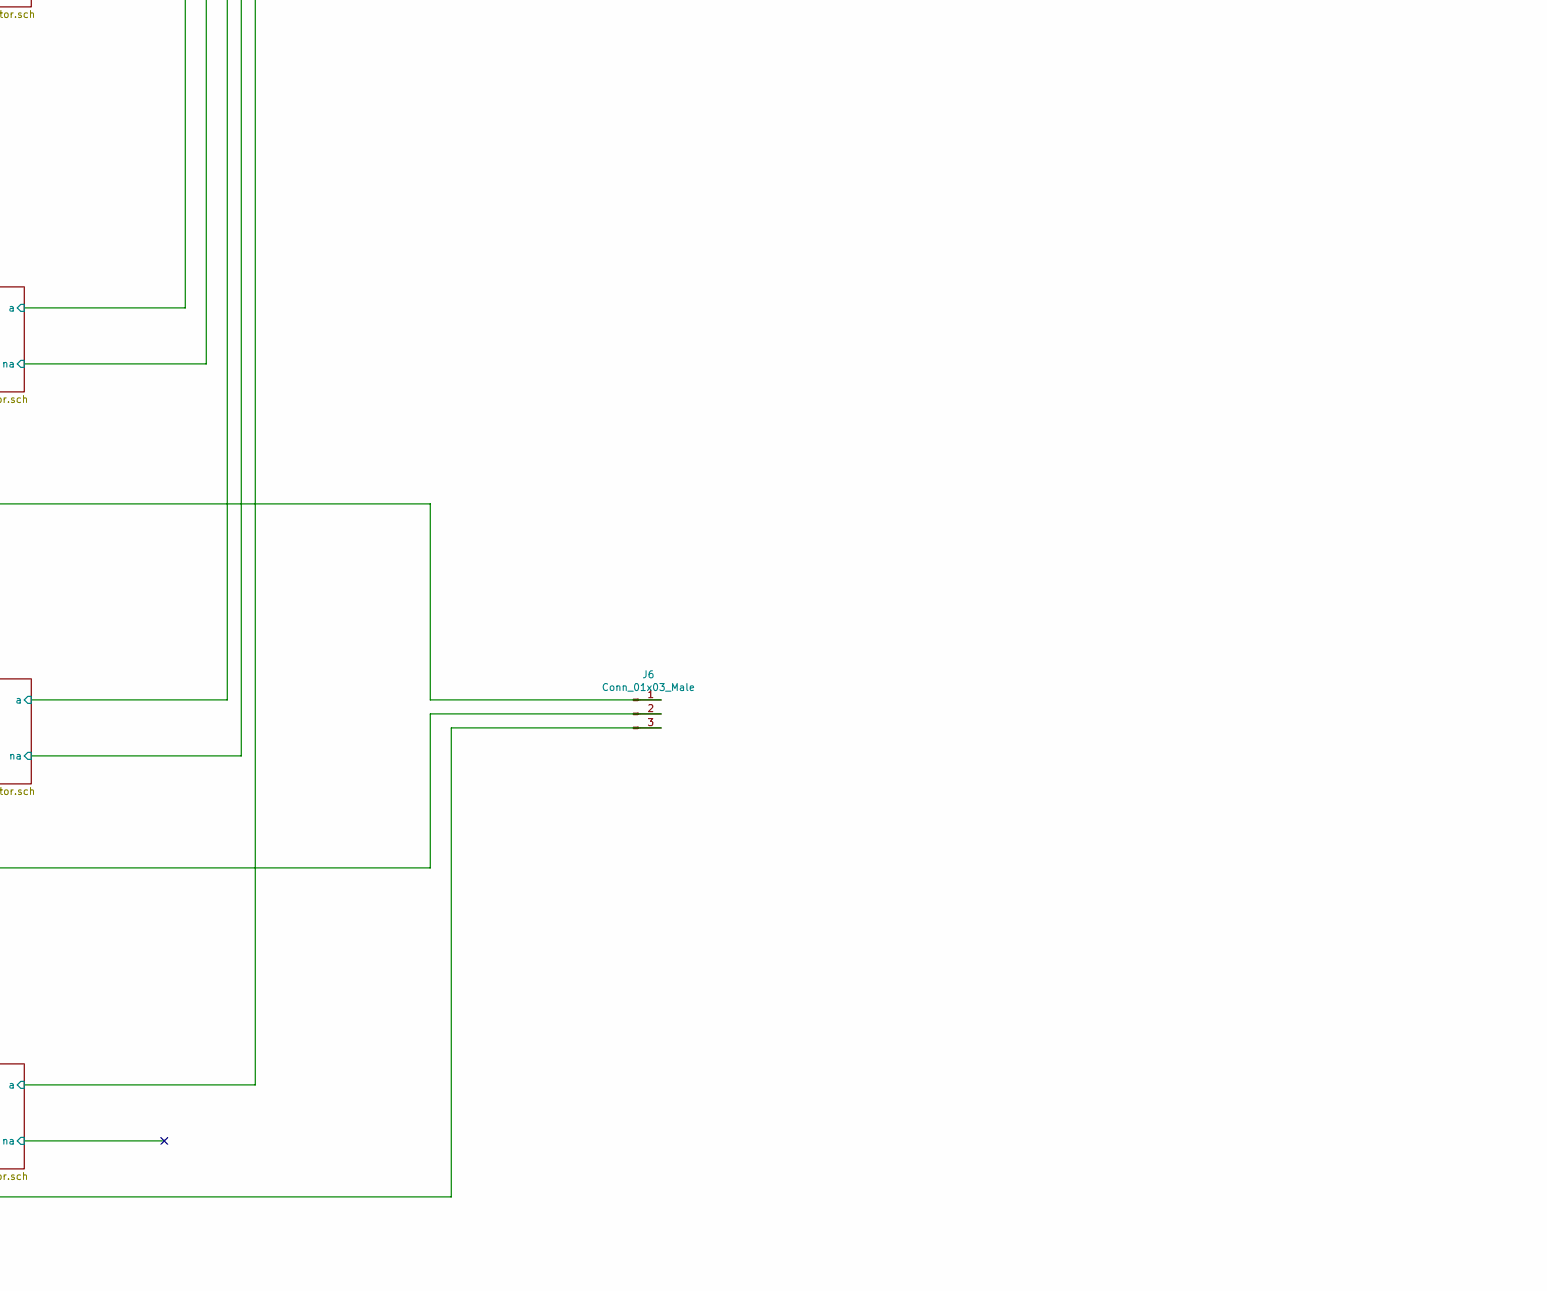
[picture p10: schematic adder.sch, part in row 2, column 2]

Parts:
J1, J2: Conn_01x06_Male; 6pin_tight
J3, J4, J16: Conn_01x01_Male; 1pin
J5, J7: Conn_01x11_Male; 11pin_tight
J6: Conn_01x03_Male; 3pin_tight
J8, J9: Conn_01x02_Male; 2pin_tight

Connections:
+5V: J8.1, J9.1; also elsewhere on the board
/Sheet63C79D9A/a: J5.1, J7.1; also elsewhere on the board
/Sheet63C79D9A/na: J5.7, J7.7; also elsewhere on the board
/Sheet63D6B888/a: J2.1; also elsewhere on the board
/Sheet63D6B888/b: J1.1; also elsewhere on the board
/Sheet63D6B888/cin: J4.1; also elsewhere on the board
/Sheet63D6B888/enable_write: J3.1, J16.1; also elsewhere on the board
/sheet63BF0A6A/a: J2.4; also elsewhere on the board
/sheet63BF0A6A/b: J1.4; also elsewhere on the board
/sheet63BF0A69/a: J2.3; also elsewhere on the board
/sheet63BF0A69/b: J1.3; also elsewhere on the board
/sheet63BF17B4/a: J2.5; also elsewhere on the board
/sheet63BF17B4/b: J1.5; also elsewhere on the board
/sheet63BF17B4/cin: J6.1; also elsewhere on the board
/sheet63BF17B5/a: J2.6; also elsewhere on the board
/sheet63BF17B5/b: J1.6; also elsewhere on the board
/sheet63BF17B5/cin: J6.2; also elsewhere on the board
/sheet63BF17B5/cout: J6.3; also elsewhere on the board
/sheet63C9D4B2/a: J5.3, J7.3; also elsewhere on the board
/sheet63C9D4B2/na: J5.9, J7.9; also elsewhere on the board
/sheet63C99497/a: J5.2, J7.2; also elsewhere on the board
/sheet63C99497/na: J5.8, J7.8; also elsewhere on the board
/sheet63CA8C9C/a: J5.5, J7.5; also elsewhere on the board
/sheet63CA8C9C/na: J5.11, J7.11; also elsewhere on the board
/sheet63CA16F0/a: J5.4, J7.4; also elsewhere on the board
/sheet63CA16F0/na: J5.10, J7.10; also elsewhere on the board
/sheet63CACA5E/a: J5.6, J7.6; also elsewhere on the board
/sheet63D7C1B8/a: J2.2; also elsewhere on the board
/sheet63D7C1B8/b: J1.2; also elsewhere on the board
GND: J8.2, J9.2; also elsewhere on the board

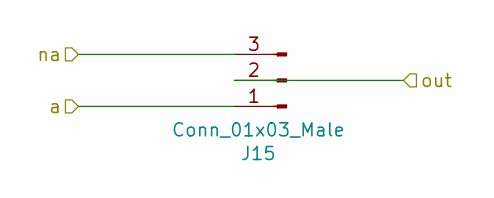
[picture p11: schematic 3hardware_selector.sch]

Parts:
J15: Conn_01x03_Male; 3hardware_selector

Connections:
/Sheet63C79D9A/a: J15.1; also elsewhere on the board
/Sheet63C79D9A/na: J15.3; also elsewhere on the board
/Sheet63C79D9A/out: J15.2; also elsewhere on the board

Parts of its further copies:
J10, J11, J12, J13, J14: Conn_01x03_Male; 3hardware_selector

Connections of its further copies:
/sheet63BF0A6A/out: J12.2; also elsewhere on the board
/sheet63BF0A69/out: J13.2; also elsewhere on the board
/sheet63BF17B4/out: J11.2; also elsewhere on the board
/sheet63BF17B5/out: J10.2; also elsewhere on the board
/sheet63C9D4B2/a: J13.1; also elsewhere on the board
/sheet63C9D4B2/na: J13.3; also elsewhere on the board
/sheet63C99497/a: J14.1; also elsewhere on the board
/sheet63C99497/na: J14.3; also elsewhere on the board
/sheet63C99497/out: J14.2; also elsewhere on the board
/sheet63CA8C9C/a: J11.1; also elsewhere on the board
/sheet63CA8C9C/na: J11.3; also elsewhere on the board
/sheet63CA16F0/a: J12.1; also elsewhere on the board
/sheet63CA16F0/na: J12.3; also elsewhere on the board
/sheet63CACA5E/a: J10.1; also elsewhere on the board

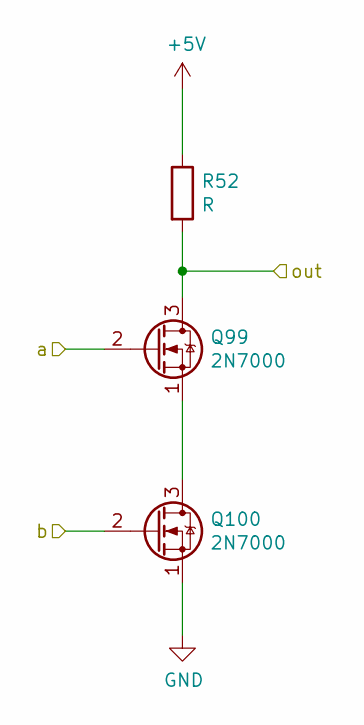
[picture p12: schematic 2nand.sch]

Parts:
Q103, Q104: 2N7000; 2n7000_tight
R54: R; resistor_tight

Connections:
+5V: R54.1; also elsewhere on the board
/Sheet63D6B888/enable_write: Q103.2 (G); also elsewhere on the board
/sheet63C99497/out: Q103.3 (D), R54.2; also elsewhere on the board
/sheet63D7C1B8/Sheet63C11D93/b: Q104.2 (G); also elsewhere on the board
GND: Q104.1 (S); also elsewhere on the board
unnamed: Q103.1 (S), Q104.3 (D)

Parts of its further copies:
Q1, Q2, Q3, Q4, Q5, Q6, Q7, Q8, Q9, Q10, Q11, Q12, Q13, Q14, Q15, Q16, Q17, Q18, Q19, Q20, Q21, Q22, Q23, Q24, Q25, Q26, Q27, Q28, Q29, Q30, Q31, Q32, Q33, Q34, Q35, Q36, Q37, Q38, Q39, Q40, Q41, Q42, Q43, Q44, Q45, Q46, Q47, Q48, Q49, Q50, Q51, Q52, Q53, Q54, Q55, Q56, Q57, Q58, Q59, Q60, Q61, Q62, Q63, Q64, Q65, Q66, Q67, Q68, Q69, Q70, Q71, Q72, Q73, Q74, Q75, Q76, Q77, Q78, Q79, Q80, Q82, Q83, Q84, Q85, Q86, Q87, Q88, Q89, Q90, Q91, Q92, Q93, Q94, Q95, Q96, Q97, Q98, Q99, Q100, Q101, Q102, Q105, Q106, Q107, Q108, Q109, Q110, Q111, Q112, Q113, Q114, Q115, Q116, Q117, Q118, Q119, Q120, Q121, Q122, Q123, Q124, Q125: 2N7000; 2n7000_tight
R1, R2, R3, R4, R5, R6, R7, R8, R9, R10, R11, R12, R13, R14, R15, R16, R18, R19, R20, R21, R22, R23, R24, R25, R26, R27, R28, R29, R30, R31, R32, R33, R34, R35, R36, R37, R38, R39, R40, R41, R42, R43, R44, R45, R46, R47, R48, R49, R50, R51, R52, R53, R55, R56, R57, R58, R59, R60, R61, R62, R63, R64, R65, R66: R; resistor_tight

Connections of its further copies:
+5V: R1.1, R2.1, R3.1, R4.1, R5.1, R6.1, R7.1, R8.1, R9.1, R10.1, R11.1, R12.1, R13.1, R14.1, R15.1, R16.1, R18.1, R19.1, R20.1, R21.1, R22.1, R23.1, R24.1, R25.1, R26.1, R27.1, R28.1, R29.1, R30.1, R31.1, R32.1, R33.1, R34.1, R35.1, R36.1, R37.1, R38.1, R39.1, R40.1, R41.1, R42.1, R43.1, R44.1, R45.1, R46.1, R47.1, R48.1, R49.1, R50.1, R51.1, R52.1, R53.1, R55.1, R56.1, R57.1, R58.1, R59.1, R60.1, R61.1, R62.1, R63.1, R64.1, R65.1, R66.1; also elsewhere on the board
/Sheet63C79D9A/out: Q124.3 (D), R65.2; also elsewhere on the board
/Sheet63D6B888/Sheet63C11D93/b: Q125.2 (G), R66.2; also elsewhere on the board
/Sheet63D6B888/Sheet63C11DD6/in: Q114.3 (D), R60.2; also elsewhere on the board
/Sheet63D6B888/a: Q116.2 (G), Q118.2 (G); also elsewhere on the board
/Sheet63D6B888/b: Q117.2 (G), Q121.2 (G); also elsewhere on the board
/Sheet63D6B888/cin: Q109.2 (G), Q113.2 (G); also elsewhere on the board
/Sheet63D6B888/enable_write: Q19.2 (G), Q40.2 (G), Q61.2 (G), Q82.2 (G), Q124.2 (G); also elsewhere on the board
/Sheet63D6B888/sheet63C11D15/Sheet63BD3FAE/sheet63BD432B/a: Q118.3 (D), Q122.2 (G), R62.2
/Sheet63D6B888/sheet63C11D15/Sheet63BD3FAE/sheet63BD432B/b: Q120.3 (D), Q123.2 (G), R63.2
/Sheet63D6B888/sheet63C11D15/sheet63BD3BA9/a: Q106.2 (G), Q116.3 (D), Q119.2 (G), Q120.2 (G), R61.2
/Sheet63D6B888/sheet63C11D15/sheet63BD3BA9/b: Q107.2 (G), Q108.3 (D), Q111.2 (G), Q112.2 (G), R57.2
/Sheet63D6B888/sheet63C11D15/sheet63BD65B1/a: Q108.2 (G), Q110.2 (G), Q122.3 (D), R64.2
/Sheet63D6B888/sheet63C11D15/sheet63BD65B1/sheet63BD432B/a: Q110.3 (D), Q114.2 (G), R58.2
/Sheet63D6B888/sheet63C11D15/sheet63BD65B1/sheet63BD432B/b: Q112.3 (D), Q115.2 (G), R59.2
/sheet63BF0A6A/Sheet63C11D93/b: Q83.2 (G), Q84.3 (D), R44.2
/sheet63BF0A6A/Sheet63C11DD6/in: Q72.3 (D), Q84.2 (G), R38.2
/sheet63BF0A6A/a: Q74.2 (G), Q76.2 (G); also elsewhere on the board
/sheet63BF0A6A/b: Q75.2 (G), Q79.2 (G); also elsewhere on the board
/sheet63BF0A6A/cin: Q1.3 (D), Q67.2 (G), Q71.2 (G), R1.2
/sheet63BF0A6A/out: Q82.3 (D), R43.2; also elsewhere on the board
/sheet63BF0A6A/sheet63C11D15/Sheet63BD3FAE/sheet63BD432B/a: Q76.3 (D), Q80.2 (G), R40.2
/sheet63BF0A6A/sheet63C11D15/Sheet63BD3FAE/sheet63BD432B/b: Q78.3 (D), R41.2; also elsewhere on the board
/sheet63BF0A6A/sheet63C11D15/sheet63BD3BA9/a: Q64.2 (G), Q74.3 (D), Q77.2 (G), Q78.2 (G), R39.2
/sheet63BF0A6A/sheet63C11D15/sheet63BD3BA9/b: Q65.2 (G), Q66.3 (D), Q69.2 (G), Q70.2 (G), R35.2
/sheet63BF0A6A/sheet63C11D15/sheet63BD65B1/a: Q66.2 (G), Q68.2 (G), Q80.3 (D), R42.2
/sheet63BF0A6A/sheet63C11D15/sheet63BD65B1/sheet63BD432B/a: Q68.3 (D), Q72.2 (G), R36.2
/sheet63BF0A6A/sheet63C11D15/sheet63BD65B1/sheet63BD432B/b: Q70.3 (D), Q73.2 (G), R37.2
/sheet63BF0A69/Sheet63C11D93/b: Q20.2 (G), Q21.3 (D), R11.2
/sheet63BF0A69/Sheet63C11DD6/in: Q9.3 (D), Q21.2 (G), R5.2
/sheet63BF0A69/a: Q11.2 (G), Q13.2 (G); also elsewhere on the board
/sheet63BF0A69/b: Q12.2 (G), Q16.2 (G); also elsewhere on the board
/sheet63BF0A69/cin: Q4.2 (G), Q8.2 (G), Q85.3 (D), R45.2
/sheet63BF0A69/out: Q19.3 (D), R10.2; also elsewhere on the board
/sheet63BF0A69/sheet63C11D15/Sheet63BD3FAE/sheet63BD432B/a: Q13.3 (D), Q17.2 (G), R7.2
/sheet63BF0A69/sheet63C11D15/Sheet63BD3FAE/sheet63BD432B/b: Q15.3 (D), Q18.2 (G), R8.2
/sheet63BF0A69/sheet63C11D15/sheet63BD3BA9/a: Q1.2 (G), Q11.3 (D), Q14.2 (G), Q15.2 (G), R6.2
/sheet63BF0A69/sheet63C11D15/sheet63BD3BA9/b: Q2.2 (G), Q3.3 (D), Q6.2 (G), Q7.2 (G), R2.2
/sheet63BF0A69/sheet63C11D15/sheet63BD65B1/a: Q3.2 (G), Q5.2 (G), Q17.3 (D), R9.2
/sheet63BF0A69/sheet63C11D15/sheet63BD65B1/sheet63BD432B/a: Q5.3 (D), Q9.2 (G), R3.2
/sheet63BF0A69/sheet63C11D15/sheet63BD65B1/sheet63BD432B/b: Q7.3 (D), Q10.2 (G), R4.2
/sheet63BF17B4/Sheet63C11D93/b: Q62.2 (G), Q63.3 (D), R33.2
/sheet63BF17B4/Sheet63C11DD6/in: Q51.3 (D), Q63.2 (G), R27.2
/sheet63BF17B4/a: Q53.2 (G), Q55.2 (G); also elsewhere on the board
/sheet63BF17B4/b: Q54.2 (G), Q58.2 (G); also elsewhere on the board
/sheet63BF17B4/cin: Q46.2 (G), Q50.2 (G), Q64.3 (D), R34.2; also elsewhere on the board
/sheet63BF17B4/out: Q61.3 (D), R32.2; also elsewhere on the board
/sheet63BF17B4/sheet63C11D15/Sheet63BD3FAE/sheet63BD432B/a: Q55.3 (D), Q59.2 (G), R29.2
/sheet63BF17B4/sheet63C11D15/Sheet63BD3FAE/sheet63BD432B/b: Q57.3 (D), Q60.2 (G), R30.2
/sheet63BF17B4/sheet63C11D15/sheet63BD3BA9/a: Q43.2 (G), Q53.3 (D), Q56.2 (G), Q57.2 (G), R28.2
/sheet63BF17B4/sheet63C11D15/sheet63BD3BA9/b: Q44.2 (G), Q45.3 (D), Q48.2 (G), Q49.2 (G), R24.2
/sheet63BF17B4/sheet63C11D15/sheet63BD65B1/a: Q45.2 (G), Q47.2 (G), Q59.3 (D), R31.2
/sheet63BF17B4/sheet63C11D15/sheet63BD65B1/sheet63BD432B/a: Q47.3 (D), Q51.2 (G), R25.2
/sheet63BF17B4/sheet63C11D15/sheet63BD65B1/sheet63BD432B/b: Q49.3 (D), Q52.2 (G), R26.2
/sheet63BF17B5/Sheet63C11D93/b: Q41.2 (G), Q42.3 (D), R22.2
/sheet63BF17B5/Sheet63C11DD6/in: Q30.3 (D), Q42.2 (G), R16.2
/sheet63BF17B5/a: Q32.2 (G), Q34.2 (G); also elsewhere on the board
/sheet63BF17B5/b: Q33.2 (G), Q37.2 (G); also elsewhere on the board
/sheet63BF17B5/cin: Q25.2 (G), Q29.2 (G), Q43.3 (D), R23.2; also elsewhere on the board
/sheet63BF17B5/cout: Q22.3 (D), R12.2; also elsewhere on the board
/sheet63BF17B5/out: Q40.3 (D), R21.2; also elsewhere on the board
/sheet63BF17B5/sheet63C11D15/Sheet63BD3FAE/sheet63BD432B/a: Q34.3 (D), Q38.2 (G), R18.2
/sheet63BF17B5/sheet63C11D15/Sheet63BD3FAE/sheet63BD432B/b: Q36.3 (D), Q39.2 (G), R19.2
/sheet63BF17B5/sheet63C11D15/sheet63BD3BA9/b: Q23.2 (G), Q24.3 (D), Q27.2 (G), Q28.2 (G), R13.2
/sheet63BF17B5/sheet63C11D15/sheet63BD65B1/a: Q24.2 (G), Q26.2 (G), Q38.3 (D), R20.2
/sheet63BF17B5/sheet63C11D15/sheet63BD65B1/sheet63BD432B/a: Q26.3 (D), Q30.2 (G), R14.2
/sheet63BF17B5/sheet63C11D15/sheet63BD65B1/sheet63BD432B/b: Q28.3 (D), Q31.2 (G), R15.2
/sheet63D7C1B8/Sheet63C11D93/b: Q105.3 (D), R55.2; also elsewhere on the board
/sheet63D7C1B8/Sheet63C11DD6/in: Q93.3 (D), Q105.2 (G), R49.2
/sheet63D7C1B8/a: Q95.2 (G), Q97.2 (G); also elsewhere on the board
/sheet63D7C1B8/b: Q96.2 (G), Q100.2 (G); also elsewhere on the board
/sheet63D7C1B8/cin: Q88.2 (G), Q92.2 (G), Q106.3 (D), R56.2
/sheet63D7C1B8/sheet63C11D15/Sheet63BD3FAE/sheet63BD432B/a: Q97.3 (D), Q101.2 (G), R51.2
/sheet63D7C1B8/sheet63C11D15/Sheet63BD3FAE/sheet63BD432B/b: Q99.3 (D), Q102.2 (G), R52.2
/sheet63D7C1B8/sheet63C11D15/sheet63BD3BA9/a: Q85.2 (G), Q95.3 (D), Q98.2 (G), Q99.2 (G), R50.2
/sheet63D7C1B8/sheet63C11D15/sheet63BD3BA9/b: Q86.2 (G), Q87.3 (D), Q90.2 (G), Q91.2 (G), R46.2
/sheet63D7C1B8/sheet63C11D15/sheet63BD65B1/a: Q87.2 (G), Q89.2 (G), Q101.3 (D), R53.2
/sheet63D7C1B8/sheet63C11D15/sheet63BD65B1/sheet63BD432B/a: Q89.3 (D), Q93.2 (G), R47.2
/sheet63D7C1B8/sheet63C11D15/sheet63BD65B1/sheet63BD432B/b: Q91.3 (D), Q94.2 (G), R48.2
GND: Q2.1 (S), Q4.1 (S), Q6.1 (S), Q8.1 (S), Q10.1 (S), Q12.1 (S), Q14.1 (S), Q16.1 (S), Q18.1 (S), Q20.1 (S), Q21.1 (S), Q23.1 (S), Q25.1 (S), Q27.1 (S), Q29.1 (S), Q31.1 (S), Q33.1 (S), Q35.1 (S), Q37.1 (S), Q39.1 (S), Q41.1 (S), Q42.1 (S), Q44.1 (S), Q46.1 (S), Q48.1 (S), Q50.1 (S), Q52.1 (S), Q54.1 (S), Q56.1 (S), Q58.1 (S), Q60.1 (S), Q62.1 (S), Q63.1 (S), Q65.1 (S), Q67.1 (S), Q69.1 (S), Q71.1 (S), Q73.1 (S), Q75.1 (S), Q77.1 (S), Q79.1 (S), Q83.1 (S), Q84.1 (S), Q86.1 (S), Q88.1 (S), Q90.1 (S), Q92.1 (S), Q94.1 (S), Q96.1 (S), Q98.1 (S), Q100.1 (S), Q102.1 (S), Q105.1 (S), Q107.1 (S), Q109.1 (S), Q111.1 (S), Q113.1 (S), Q115.1 (S), Q117.1 (S), Q119.1 (S), Q121.1 (S), Q123.1 (S), Q125.1 (S); also elsewhere on the board
unnamed: Q1.1 (S), Q2.3 (D)
unnamed: Q3.1 (S), Q4.3 (D)
unnamed: Q5.1 (S), Q6.3 (D)
unnamed: Q7.1 (S), Q8.3 (D)
unnamed: Q9.1 (S), Q10.3 (D)
unnamed: Q11.1 (S), Q12.3 (D)
unnamed: Q13.1 (S), Q14.3 (D)
unnamed: Q15.1 (S), Q16.3 (D)
unnamed: Q17.1 (S), Q18.3 (D)
unnamed: Q19.1 (S), Q20.3 (D)
unnamed: Q22.1 (S), Q23.3 (D)
unnamed: Q24.1 (S), Q25.3 (D)
unnamed: Q26.1 (S), Q27.3 (D)
unnamed: Q28.1 (S), Q29.3 (D)
unnamed: Q30.1 (S), Q31.3 (D)
unnamed: Q32.1 (S), Q33.3 (D)
unnamed: Q34.1 (S), Q35.3 (D)
unnamed: Q36.1 (S), Q37.3 (D)
unnamed: Q38.1 (S), Q39.3 (D)
unnamed: Q40.1 (S), Q41.3 (D)
unnamed: Q43.1 (S), Q44.3 (D)
unnamed: Q45.1 (S), Q46.3 (D)
unnamed: Q47.1 (S), Q48.3 (D)
unnamed: Q49.1 (S), Q50.3 (D)
unnamed: Q51.1 (S), Q52.3 (D)
unnamed: Q53.1 (S), Q54.3 (D)
unnamed: Q55.1 (S), Q56.3 (D)
unnamed: Q57.1 (S), Q58.3 (D)
unnamed: Q59.1 (S), Q60.3 (D)
unnamed: Q61.1 (S), Q62.3 (D)
unnamed: Q64.1 (S), Q65.3 (D)
unnamed: Q66.1 (S), Q67.3 (D)
unnamed: Q68.1 (S), Q69.3 (D)
unnamed: Q70.1 (S), Q71.3 (D)
unnamed: Q72.1 (S), Q73.3 (D)
unnamed: Q74.1 (S), Q75.3 (D)
unnamed: Q76.1 (S), Q77.3 (D)
unnamed: Q78.1 (S), Q79.3 (D)
unnamed: Q82.1 (S), Q83.3 (D)
unnamed: Q85.1 (S), Q86.3 (D)
unnamed: Q87.1 (S), Q88.3 (D)
unnamed: Q89.1 (S), Q90.3 (D)
unnamed: Q91.1 (S), Q92.3 (D)
unnamed: Q93.1 (S), Q94.3 (D)
unnamed: Q95.1 (S), Q96.3 (D)
unnamed: Q97.1 (S), Q98.3 (D)
unnamed: Q99.1 (S), Q100.3 (D)
unnamed: Q101.1 (S), Q102.3 (D)
unnamed: Q106.1 (S), Q107.3 (D)
unnamed: Q108.1 (S), Q109.3 (D)
unnamed: Q110.1 (S), Q111.3 (D)
unnamed: Q112.1 (S), Q113.3 (D)
unnamed: Q114.1 (S), Q115.3 (D)
unnamed: Q116.1 (S), Q117.3 (D)
unnamed: Q118.1 (S), Q119.3 (D)
unnamed: Q120.1 (S), Q121.3 (D)
unnamed: Q122.1 (S), Q123.3 (D)
unnamed: Q124.1 (S), Q125.3 (D)

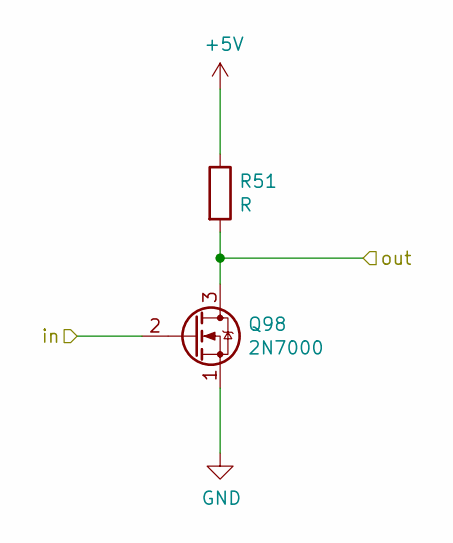
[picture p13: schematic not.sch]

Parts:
Q81: 2N7000; 2n7000_tight
R17: R; resistor_tight

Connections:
+5V: R17.1; also elsewhere on the board
/sheet63BF0A6A/sheet63C11D15/Sheet63BD3FAE/sheet63BD432B/b: Q81.2 (G); also elsewhere on the board
GND: Q81.1 (S); also elsewhere on the board

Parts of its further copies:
Q1, Q8, Q9, Q10, Q11, Q12, Q13, Q14, Q15, Q16, Q17, Q18, Q19, Q20, Q21, Q22, Q23, Q24, Q25, Q26, Q27, Q28, Q29, Q30, Q31, Q32, Q33, Q34, Q40, Q41, Q42, Q46, Q47, Q48, Q49, Q50, Q51, Q52, Q53, Q54, Q55, Q56, Q62, Q63, Q74, Q75, Q76, Q78, Q79, Q80, Q82, Q83, Q84, Q85, Q88, Q90, Q91, Q92, Q93, Q95, Q98, Q105, Q106, Q107, Q108, Q109, Q110, Q111, Q112, Q113, Q114, Q115, Q117, Q126: 2N7000; 2n7000_tight
R5, R6, R7, R8, R9, R10, R11, R16, R18, R19, R20, R21, R22, R23, R24, R25, R26, R27, R28, R29, R30, R31, R32, R33, R34, R35, R36, R37, R38, R39, R40, R41, R42, R43, R44, R45, R46, R48, R49, R51, R55, R60, R61, R62, R63, R64, R65, R66, R67, R68, R69, R70, R72: R; resistor_tight

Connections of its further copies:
+5V: R5.1, R6.1, R7.1, R8.1, R9.1, R10.1, R11.1, R16.1, R18.1, R19.1, R20.1, R21.1, R22.1, R23.1, R24.1, R25.1, R26.1, R27.1, R28.1, R29.1, R30.1, R31.1, R32.1, R33.1, R34.1, R35.1, R36.1, R37.1, R38.1, R39.1, R40.1, R41.1, R42.1, R43.1, R44.1, R45.1, R46.1, R48.1, R49.1, R51.1, R55.1, R60.1, R61.1, R62.1, R63.1, R64.1, R65.1, R66.1; also elsewhere on the board
/Sheet63C79D9A/out: R65.2; also elsewhere on the board
/Sheet63D6B888/Sheet63C11D93/b: Q126.3 (D), R66.2; also elsewhere on the board
/Sheet63D6B888/Sheet63C11DD6/in: Q114.3 (D), Q126.2 (G), R60.2
/Sheet63D6B888/b: Q117.2 (G); also elsewhere on the board
/Sheet63D6B888/cin: Q109.2 (G), Q113.2 (G); also elsewhere on the board
/Sheet63D6B888/enable_write: Q19.2 (G), Q40.2 (G), Q82.2 (G); also elsewhere on the board
/Sheet63D6B888/sheet63C11D15/Sheet63BD3FAE/sheet63BD432B/a: R62.2; also elsewhere on the board
/Sheet63D6B888/sheet63C11D15/Sheet63BD3FAE/sheet63BD432B/b: R63.2; also elsewhere on the board
/Sheet63D6B888/sheet63C11D15/sheet63BD3BA9/a: Q106.2 (G), R61.2; also elsewhere on the board
/Sheet63D6B888/sheet63C11D15/sheet63BD3BA9/b: Q107.2 (G), Q108.3 (D), Q111.2 (G), Q112.2 (G); also elsewhere on the board
/Sheet63D6B888/sheet63C11D15/sheet63BD65B1/a: Q108.2 (G), Q110.2 (G), R64.2; also elsewhere on the board
/Sheet63D6B888/sheet63C11D15/sheet63BD65B1/sheet63BD432B/a: Q110.3 (D), Q114.2 (G); also elsewhere on the board
/Sheet63D6B888/sheet63C11D15/sheet63BD65B1/sheet63BD432B/b: Q112.3 (D), Q115.2 (G); also elsewhere on the board
/sheet63BF0A6A/Sheet63C11D93/b: Q83.2 (G), Q84.3 (D), R44.2
/sheet63BF0A6A/Sheet63C11DD6/in: Q84.2 (G), R38.2; also elsewhere on the board
/sheet63BF0A6A/a: Q74.2 (G), Q76.2 (G); also elsewhere on the board
/sheet63BF0A6A/b: Q75.2 (G), Q79.2 (G); also elsewhere on the board
/sheet63BF0A6A/cin: Q1.3 (D); also elsewhere on the board
/sheet63BF0A6A/out: Q82.3 (D), R43.2; also elsewhere on the board
/sheet63BF0A6A/sheet63C11D15/Sheet63BD3FAE/sheet63BD432B/a: Q76.3 (D), Q80.2 (G), R40.2
/sheet63BF0A6A/sheet63C11D15/Sheet63BD3FAE/sheet63BD432B/b: Q78.3 (D), R41.2; also elsewhere on the board
/sheet63BF0A6A/sheet63C11D15/sheet63BD3BA9/a: Q74.3 (D), Q78.2 (G), R39.2; also elsewhere on the board
/sheet63BF0A6A/sheet63C11D15/sheet63BD3BA9/b: R35.2; also elsewhere on the board
/sheet63BF0A6A/sheet63C11D15/sheet63BD65B1/a: Q80.3 (D), R42.2; also elsewhere on the board
/sheet63BF0A6A/sheet63C11D15/sheet63BD65B1/sheet63BD432B/a: R36.2; also elsewhere on the board
/sheet63BF0A6A/sheet63C11D15/sheet63BD65B1/sheet63BD432B/b: R37.2; also elsewhere on the board
/sheet63BF0A69/Sheet63C11D93/b: Q20.2 (G), Q21.3 (D), R11.2
/sheet63BF0A69/Sheet63C11DD6/in: Q9.3 (D), Q21.2 (G), R5.2
/sheet63BF0A69/a: Q11.2 (G), Q13.2 (G); also elsewhere on the board
/sheet63BF0A69/b: Q12.2 (G), Q16.2 (G); also elsewhere on the board
/sheet63BF0A69/cin: Q8.2 (G), Q85.3 (D), R45.2; also elsewhere on the board
/sheet63BF0A69/out: Q19.3 (D), R10.2; also elsewhere on the board
/sheet63BF0A69/sheet63C11D15/Sheet63BD3FAE/sheet63BD432B/a: Q13.3 (D), Q17.2 (G), R7.2
/sheet63BF0A69/sheet63C11D15/Sheet63BD3FAE/sheet63BD432B/b: Q15.3 (D), Q18.2 (G), R8.2
/sheet63BF0A69/sheet63C11D15/sheet63BD3BA9/a: Q1.2 (G), Q11.3 (D), Q14.2 (G), Q15.2 (G), R6.2
/sheet63BF0A69/sheet63C11D15/sheet63BD65B1/a: Q17.3 (D), R9.2; also elsewhere on the board
/sheet63BF0A69/sheet63C11D15/sheet63BD65B1/sheet63BD432B/a: Q9.2 (G); also elsewhere on the board
/sheet63BF0A69/sheet63C11D15/sheet63BD65B1/sheet63BD432B/b: Q10.2 (G); also elsewhere on the board
/sheet63BF17B4/Sheet63C11D93/b: Q62.2 (G), Q63.3 (D), R33.2
/sheet63BF17B4/Sheet63C11DD6/in: Q51.3 (D), Q63.2 (G), R27.2
/sheet63BF17B4/a: Q53.2 (G), Q55.2 (G); also elsewhere on the board
/sheet63BF17B4/b: Q54.2 (G); also elsewhere on the board
/sheet63BF17B4/cin: Q46.2 (G), Q50.2 (G), R34.2; also elsewhere on the board
/sheet63BF17B4/out: R32.2; also elsewhere on the board
/sheet63BF17B4/sheet63C11D15/Sheet63BD3FAE/sheet63BD432B/a: Q55.3 (D), R29.2; also elsewhere on the board
/sheet63BF17B4/sheet63C11D15/Sheet63BD3FAE/sheet63BD432B/b: R30.2; also elsewhere on the board
/sheet63BF17B4/sheet63C11D15/sheet63BD3BA9/a: Q53.3 (D), Q56.2 (G), R28.2; also elsewhere on the board
/sheet63BF17B4/sheet63C11D15/sheet63BD3BA9/b: Q48.2 (G), Q49.2 (G), R24.2; also elsewhere on the board
/sheet63BF17B4/sheet63C11D15/sheet63BD65B1/a: Q47.2 (G), R31.2; also elsewhere on the board
/sheet63BF17B4/sheet63C11D15/sheet63BD65B1/sheet63BD432B/a: Q47.3 (D), Q51.2 (G), R25.2
/sheet63BF17B4/sheet63C11D15/sheet63BD65B1/sheet63BD432B/b: Q49.3 (D), Q52.2 (G), R26.2
/sheet63BF17B5/Sheet63C11D93/b: Q41.2 (G), Q42.3 (D), R22.2
/sheet63BF17B5/Sheet63C11DD6/in: Q30.3 (D), Q42.2 (G), R16.2
/sheet63BF17B5/a: Q32.2 (G), Q34.2 (G); also elsewhere on the board
/sheet63BF17B5/b: Q33.2 (G); also elsewhere on the board
/sheet63BF17B5/cin: Q25.2 (G), Q29.2 (G), R23.2; also elsewhere on the board
/sheet63BF17B5/cout: Q22.3 (D); also elsewhere on the board
/sheet63BF17B5/out: Q40.3 (D), R21.2; also elsewhere on the board
/sheet63BF17B5/sheet63C11D15/Sheet63BD3FAE/sheet63BD432B/a: Q34.3 (D), R18.2; also elsewhere on the board
/sheet63BF17B5/sheet63C11D15/Sheet63BD3FAE/sheet63BD432B/b: R19.2; also elsewhere on the board
/sheet63BF17B5/sheet63C11D15/sheet63BD3BA9/b: Q23.2 (G), Q24.3 (D), Q27.2 (G), Q28.2 (G); also elsewhere on the board
/sheet63BF17B5/sheet63C11D15/sheet63BD65B1/a: Q24.2 (G), Q26.2 (G), R20.2; also elsewhere on the board
/sheet63BF17B5/sheet63C11D15/sheet63BD65B1/sheet63BD432B/a: Q26.3 (D), Q30.2 (G); also elsewhere on the board
/sheet63BF17B5/sheet63C11D15/sheet63BD65B1/sheet63BD432B/b: Q28.3 (D), Q31.2 (G); also elsewhere on the board
/sheet63D7C1B8/Sheet63C11D93/b: Q105.3 (D), R55.2; also elsewhere on the board
/sheet63D7C1B8/Sheet63C11DD6/in: Q93.3 (D), Q105.2 (G), R49.2
/sheet63D7C1B8/a: Q95.2 (G); also elsewhere on the board
/sheet63D7C1B8/cin: Q88.2 (G), Q92.2 (G), Q106.3 (D); also elsewhere on the board
/sheet63D7C1B8/sheet63C11D15/Sheet63BD3FAE/sheet63BD432B/a: R51.2; also elsewhere on the board
/sheet63D7C1B8/sheet63C11D15/sheet63BD3BA9/a: Q85.2 (G), Q95.3 (D), Q98.2 (G); also elsewhere on the board
/sheet63D7C1B8/sheet63C11D15/sheet63BD3BA9/b: Q90.2 (G), Q91.2 (G), R46.2; also elsewhere on the board
/sheet63D7C1B8/sheet63C11D15/sheet63BD65B1/sheet63BD432B/a: Q93.2 (G); also elsewhere on the board
/sheet63D7C1B8/sheet63C11D15/sheet63BD65B1/sheet63BD432B/b: Q91.3 (D), R48.2; also elsewhere on the board
GND: Q8.1 (S), Q10.1 (S), Q12.1 (S), Q14.1 (S), Q16.1 (S), Q18.1 (S), Q20.1 (S), Q21.1 (S), Q23.1 (S), Q25.1 (S), Q27.1 (S), Q29.1 (S), Q31.1 (S), Q33.1 (S), Q41.1 (S), Q42.1 (S), Q46.1 (S), Q48.1 (S), Q50.1 (S), Q52.1 (S), Q54.1 (S), Q56.1 (S), Q62.1 (S), Q63.1 (S), Q75.1 (S), Q79.1 (S), Q83.1 (S), Q84.1 (S), Q88.1 (S), Q90.1 (S), Q92.1 (S), Q98.1 (S), Q105.1 (S), Q107.1 (S), Q109.1 (S), Q111.1 (S), Q113.1 (S), Q115.1 (S), Q117.1 (S), Q126.1 (S); also elsewhere on the board
unnamed 92: Q1.1 (S); also elsewhere on the board
unnamed 95: Q8.3 (D); also elsewhere on the board
unnamed: Q9.1 (S), Q10.3 (D)
unnamed: Q11.1 (S), Q12.3 (D)
unnamed: Q13.1 (S), Q14.3 (D)
unnamed: Q15.1 (S), Q16.3 (D)
unnamed: Q17.1 (S), Q18.3 (D)
unnamed: Q19.1 (S), Q20.3 (D)
unnamed: Q22.1 (S), Q23.3 (D)
unnamed: Q24.1 (S), Q25.3 (D)
unnamed: Q26.1 (S), Q27.3 (D)
unnamed: Q28.1 (S), Q29.3 (D)
unnamed: Q30.1 (S), Q31.3 (D)
unnamed: Q32.1 (S), Q33.3 (D)
unnamed 108: Q34.1 (S); also elsewhere on the board
unnamed: Q40.1 (S), Q41.3 (D)
unnamed 113: Q46.3 (D); also elsewhere on the board
unnamed: Q47.1 (S), Q48.3 (D)
unnamed: Q49.1 (S), Q50.3 (D)
unnamed: Q51.1 (S), Q52.3 (D)
unnamed: Q53.1 (S), Q54.3 (D)
unnamed: Q55.1 (S), Q56.3 (D)
unnamed 121: Q62.3 (D); also elsewhere on the board
unnamed: Q74.1 (S), Q75.3 (D)
unnamed 128: Q76.1 (S); also elsewhere on the board
unnamed: Q78.1 (S), Q79.3 (D)
unnamed: Q82.1 (S), Q83.3 (D)
unnamed 131: Q85.1 (S); also elsewhere on the board
unnamed 132: Q88.3 (D); also elsewhere on the board
unnamed 133: Q90.3 (D); also elsewhere on the board
unnamed: Q91.1 (S), Q92.3 (D)
unnamed 135: Q93.1 (S); also elsewhere on the board
unnamed 136: Q95.1 (S); also elsewhere on the board
unnamed 137: Q98.3 (D); also elsewhere on the board
unnamed: Q106.1 (S), Q107.3 (D)
unnamed: Q108.1 (S), Q109.3 (D)
unnamed: Q110.1 (S), Q111.3 (D)
unnamed: Q112.1 (S), Q113.3 (D)
unnamed: Q114.1 (S), Q115.3 (D)
unnamed 146: Q117.3 (D); also elsewhere on the board

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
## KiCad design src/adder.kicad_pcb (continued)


Board: 2 copper layers, 100.0 x 100.0 mm, 208 parts (0 on the bottom side), 153 nets.

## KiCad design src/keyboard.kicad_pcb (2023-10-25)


Board: 2 copper layers, 100.0 x 100.0 mm, 103 parts (0 on the bottom side), 48 nets.

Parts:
C1, C2, C3, C4, C5, C6, C7: C; capacitor
D1, D2, D3, D4, D5, D6, D7: LED; led_5mm_tight
J1: Conn_01x01_Male; 1pin
J2, J3: Conn_01x02_Male; 2pin_tight
J4, J5: Conn_01x11_Male; 11pin_tight
Q1, Q2, Q3, Q4, Q5, Q6, Q7, Q8, Q9, Q10, Q11, Q12, Q13, Q14, Q15, Q16, Q17, Q19, Q20, Q21, Q22, Q23, Q24, Q25: 2N7000; 2n7000_tight
R1, R2, R3, R4, R5, R6, R7, R8, R9, R10, R11, R12, R13, R14, R15, R16, R17, R18, R19, R27, R28, R29, R30, R31, R32: R; resistor_tight
R20, R21, R22, R23, R24, R25, R26: R; resistor_led_tight
SW1, SW2, SW3, SW4, SW5, SW6, SW7, SW8, SW9, SW10, SW11, SW12, SW13, SW14, SW15, SW16, SW17, SW18, SW19, SW20, SW21, SW22, SW23, SW24, SW25, SW26, SW27, SW28: SW_Push_DPDT; dpdt_switch

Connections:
+5V: D1.2, D2.2, D3.2, D4.2, D5.2, D6.2, D7.2, J2.1, J3.1, R8.1, R9.1, R10.1, R11.1, R12.1, R13.1, R14.1, R15.1, R16.1, R17.1, R18.1, R19.1, R27.1, R28.1, R29.1, R30.1, R31.1, R32.1
/Sheet63C33C3A/a: J1.1, Q1.2, Q3.2, Q5.2, Q7.2, Q9.2, Q17.2, Q19.2, Q21.2, Q23.2, Q24.2, Q25.2
/Sheet63C33C3A/out: J4.1, J5.1, Q1.3, R15.2
/Sheet63C1613A/a: C3.1, Q2.2, Q10.2, R3.2
/Sheet63C1613A/b: C2.1, Q4.2, Q11.2, R2.2
/Sheet63C1613A/sheet63C18FE1/a: R3.1, R8.2, SW1.2, SW1.5, SW2.2, SW3.2, SW4.2, SW5.2, SW6.2, SW7.2, SW8.5, SW14.5, SW19.5, SW23.5, SW26.5, SW28.5
/Sheet63C1613A/sheet63C18FE1/b: R2.1, R9.2, SW2.5, SW8.2, SW9.2, SW9.5, SW10.2, SW11.2, SW12.2, SW13.2, SW15.5, SW20.5, SW24.5, SW27.5
/Sheet63C1613A/sheet63C18FE1/c: R1.1, R10.2, SW3.5, SW10.5, SW14.2, SW15.2, SW16.2, SW16.5, SW17.2, SW18.2, SW21.5, SW25.5
/Sheet63C1613A/sheet63C18FE1/d: R11.2, SW4.5, SW11.5, SW17.5, SW19.2, SW20.2, SW21.2, SW22.2, SW22.5
/Sheet63C1613A/sheet63C18FE1/e: R4.1, R12.2, SW5.5, SW12.5, SW18.5, SW23.2, SW24.2, SW25.2
/Sheet63C1613A/sheet63C18FE1/f: R6.1, R13.2, SW6.5, SW13.5, SW26.2, SW27.2
/Sheet63C1613A/sheet63C18FE1/g: R7.1, R14.2, SW7.5, SW28.2
/Sheet63CC3F40/out: J4.8, J5.8, Q9.3, R19.2
/sheet63C34C32/b: C7.1, Q16.2, Q22.2, R7.2
/sheet63C34C32/out: J4.7, J5.7, Q21.3, R29.2
/sheet63C342CE/out: J4.2, J5.2, Q3.3, R16.2
/sheet63C343CC/b: C1.1, Q6.2, Q12.2, R1.2
/sheet63C343CC/out: J4.3, J5.3, Q5.3, R17.2
/sheet63C348D6/b: C5.1, Q8.2, Q13.2, R5.2
/sheet63C348D6/out: J4.4, J5.4, Q7.3, R18.2
/sheet63C348D7/b: C4.1, Q14.2, R4.2
/sheet63C348D7/out: J4.5, J5.5, Q17.3, R27.2
/sheet63C348D8/b: C6.1, Q15.2, Q20.2, R6.2
/sheet63C348D8/out: J4.6, J5.6, Q19.3, R28.2
/sheet63E7D33C/out: J4.11, J5.11, Q25.3, R32.2
/sheet63E76C8C/out: J4.9, J5.9, Q23.3, R30.2
/sheet63E79FE1/out: J4.10, J5.10, Q24.3, R31.2
GND: C1.2, C2.2, C3.2, C4.2, C5.2, C6.2, C7.2, J2.2, J3.2, Q2.1, Q4.1, Q6.1, Q8.1, Q9.1, Q20.1, Q22.1, Q23.1, Q24.1, Q25.1, R20.2, R21.2, R22.2, R23.2, R24.2, R25.2, R26.2, SW1.3, SW1.6, SW2.3, SW2.6, SW3.3, SW3.6, SW4.3, SW4.6, SW5.3, SW5.6, SW6.3, SW6.6, SW7.3, SW7.6, SW8.3, SW8.6, SW9.3, SW9.6, SW10.3, SW10.6, SW11.3, SW11.6, SW12.3, SW12.6, SW13.3, SW13.6, SW14.3, SW14.6, SW15.3, SW15.6, SW16.3, SW16.6, SW17.3, SW17.6, SW18.3, SW18.6, SW19.3, SW19.6, SW20.3, SW20.6, SW21.3, SW21.6, SW22.3, SW22.6, SW23.3, SW23.6, SW24.3, SW24.6, SW25.3, SW25.6, SW26.3, SW26.6, SW27.3, SW27.6, SW28.3, SW28.6
unnamed: D1.1, Q10.3
unnamed: D2.1, Q11.3
unnamed: D3.1, Q12.3
unnamed: D4.1, Q13.3
unnamed: D5.1, Q14.3
unnamed: D6.1, Q15.3
unnamed: D7.1, Q16.3
unnamed: Q1.1, Q2.3
unnamed: Q3.1, Q4.3
unnamed: Q5.1, Q6.3
unnamed: Q7.1, Q8.3
unnamed: Q10.1, R20.1
unnamed: Q11.1, R21.1
unnamed: Q12.1, R22.1
unnamed: Q13.1, R23.1
unnamed: Q14.1, R24.1
unnamed: Q15.1, R25.1
unnamed: Q16.1, R26.1
unnamed: Q19.1, Q20.3
unnamed: Q21.1, Q22.3

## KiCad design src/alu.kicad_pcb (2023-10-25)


Board: 2 copper layers, 100.0 x 100.0 mm, 157 parts (0 on the bottom side), 100 nets.

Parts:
D1, D2, D3, D4, D5, D6, D7, D8: LED; led_5mm_tight
J1: add; 2pin_tight
J2: carry; 2pin_tight
J3: pc+1; 2pin_tight
J4: sp offset; 2pin_tight
J5, J6, J7, J8, J9, J12: Conn_01x11_Male; 11pin_tight
J10, J11: Conn_01x02_Male; 2pin_tight
J13: alu_sel; 3pin_tight
Q1, Q2, Q3, Q4, Q5, Q6, Q7, Q8, Q9, Q10, Q11, Q12, Q13, Q14, Q15, Q16, Q17, Q18, Q19, Q20, Q21, Q22, Q23, Q24, Q25, Q26, Q27, Q28, Q29, Q30, Q31, Q32, Q33, Q34, Q35, Q36, Q37, Q38, Q39, Q40, Q41, Q42, Q43, Q44, Q45, Q46, Q47, Q48, Q49, Q50, Q51, Q52, Q53, Q54, Q55, Q56, Q57, Q58, Q59, Q60, Q61, Q62, Q63, Q64, Q65, Q66, Q67, Q68, Q69, Q70, Q71, Q72, Q73, Q74, Q75, Q76, Q77, Q78, Q79, Q80, Q81, Q82, Q83, Q84, Q85, Q86, Q87, Q88, Q89, Q90, Q91, Q92, Q93: 2N7000; 2n7000_tight
R1, R2, R3, R4, R5, R6, R7, R8, R9, R10, R11, R12, R13, R14, R15, R16, R17, R18, R19, R20, R21, R22, R29, R30, R31, R32, R33, R34, R35, R36, R37, R38, R39, R42, R43: R; resistor_tight
R23, R24, R25, R26, R27, R28, R40, R41: R; resistor_led_tight

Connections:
+5V: D1.2, D2.2, D3.2, D4.2, D5.2, D6.2, D7.2, D8.2, J10.1, J11.1, R1.1, R2.1, R3.1, R4.1, R5.1, R6.1, R7.1, R8.1, R9.1, R10.1, R11.1, R12.1, R13.1, R14.1, R15.1, R16.1, R17.1, R18.1, R19.1, R20.1, R21.1, R22.1, R29.1, R30.1, R31.1, R32.1, R33.1, R34.1, R35.1, R36.1, R37.1, R38.1, R39.1, R42.1, R43.1
/Sheet63BFA3AE/Sheet63BAB2B1/a: Q62.2, Q65.2, Q68.2, Q71.2, Q74.3, R33.2
/Sheet63BFA3AE/Sheet63BAB2B1/b: Q63.2, Q66.2, Q75.3, Q78.2, Q81.2, R34.2
/Sheet63BFA3AE/Sheet63BAB2B1/c: Q64.2, Q70.2, Q76.3, Q79.2, Q85.2, R35.2
/Sheet63BFA3AE/a: Q86.3, Q87.3, Q88.3, Q89.2, R39.2
/Sheet63BFA3AE/ain: J13.1, Q74.2, Q77.2, Q80.2, Q83.2, Q86.2
/Sheet63BFA3AE/bin: J13.2, Q69.2, Q72.2, Q75.2, Q84.2, Q87.2
/Sheet63BFA3AE/cin: J13.3, Q67.2, Q73.2, Q76.2, Q82.2, Q88.2
/Sheet63BFA3AE/d: J3.1, J3.2, Q58.2, Q77.3, Q78.3, Q79.3, R36.2
/Sheet63BFA3AE/e: J4.1, J4.2, Q59.2, Q71.3, Q72.3, Q73.3, R32.2
/Sheet63BFA3AE/h: Q62.3, Q63.3, Q64.3, Q90.2, R29.2
/Sheet63BFDF12/a0: J6.1, J9.1, Q2.2, Q35.2
/Sheet63BFDF12/a1: J6.2, J9.2, Q5.2, Q37.2
/Sheet63BFDF12/a2: J6.3, J9.3, Q11.2, Q39.2
/Sheet63BFDF12/a3: J6.4, J9.4, Q14.2, Q41.2
/Sheet63BFDF12/a4: J6.5, J9.5, Q17.2, Q43.2
/Sheet63BFDF12/a5: J6.6, J9.6, Q20.2, Q45.2
/Sheet63BFDF12/a6: J6.7, J9.7, Q23.2, Q47.2
/Sheet63BFDF12/a7: J6.8, J9.8, Q26.2, Q49.2
/Sheet63BFDF12/a8: J6.9, J9.9, Q29.2, Q51.2
/Sheet63BFDF12/a9: J6.10, J9.10, Q32.2, Q53.2
/Sheet63BFDF12/a10: J6.11, J9.11, Q8.2, Q55.2
/Sheet63BFDF12/b0: J7.1, J12.1, Q3.2
/Sheet63BFDF12/b1: J7.2, J12.2, Q6.2
/Sheet63BFDF12/b2: J7.3, J12.3, Q12.2
/Sheet63BFDF12/b3: J7.4, J12.4, Q15.2
/Sheet63BFDF12/b4: J7.5, J12.5, Q18.2
/Sheet63BFDF12/b5: J7.6, J12.6, Q21.2
/Sheet63BFDF12/b6: J7.7, J12.7, Q24.2
/Sheet63BFDF12/b7: J7.8, J12.8, Q27.2
/Sheet63BFDF12/b8: J7.9, J12.9, Q30.2
/Sheet63BFDF12/b9: J7.10, J12.10, Q33.2
/Sheet63BFDF12/b10: J7.11, J12.11, Q9.2
/Sheet63BFDF12/enable: Q1.2, Q4.2, Q7.2, Q10.2, Q13.2, Q16.2, Q19.2, Q22.2, Q25.2, Q28.2, Q31.2, Q60.2, Q68.3, Q69.3, Q70.3, R31.2
/Sheet63BFDF12/out0: J5.1, J8.1, Q1.3, Q34.3, R1.2, R12.2
/Sheet63BFDF12/out1: J5.2, J8.2, Q4.3, Q36.3, R2.2, R13.2
/Sheet63BFDF12/out2: J5.3, J8.3, Q10.3, Q38.3, R4.2, R14.2
/Sheet63BFDF12/out3: J5.4, J8.4, Q13.3, Q40.3, R5.2, R15.2
/Sheet63BFDF12/out4: J5.5, J8.5, Q16.3, Q42.3, R6.2, R16.2
/Sheet63BFDF12/out5: J5.6, J8.6, Q19.3, Q44.3, R7.2, R17.2
/Sheet63BFDF12/out6: J5.7, J8.7, Q22.3, Q46.3, R8.2, R18.2
/Sheet63BFDF12/out7: J5.8, J8.8, Q25.3, Q48.3, R9.2, R19.2
/Sheet63BFDF12/out8: J5.9, J8.9, Q28.3, Q50.3, R10.2, R20.2
/Sheet63BFDF12/out9: J5.10, J8.10, Q31.3, Q52.3, R11.2, R21.2
/Sheet63BFDF12/out10: J5.11, J8.11, Q7.3, Q54.3, R3.2, R22.2
/Sheet648070F7/a: Q56.2, Q83.3, Q84.3, Q85.3, Q91.2, R38.2
/Sheet648070F7/b: J2.1, J2.2, Q57.2, Q80.3, Q81.3, Q82.3, Q92.2, R37.2
/Sheet64807415/in: Q91.3, Q92.3, Q93.2, R42.2
/Sheet64807415/out: J1.1, J1.2, Q93.3, R43.2
/sheet63E1DFB6/enable: Q34.2, Q36.2, Q38.2, Q40.2, Q42.2, Q44.2, Q46.2, Q48.2, Q50.2, Q52.2, Q54.2, Q61.2, Q65.3, Q66.3, Q67.3, R30.2
GND: J10.2, J11.2, Q3.1, Q6.1, Q9.1, Q12.1, Q15.1, Q18.1, Q21.1, Q24.1, Q27.1, Q30.1, Q33.1, Q35.1, Q37.1, Q39.1, Q41.1, Q43.1, Q45.1, Q47.1, Q49.1, Q51.1, Q53.1, Q55.1, Q62.1, Q63.1, Q64.1, Q65.1, Q66.1, Q67.1, Q68.1, Q69.1, Q70.1, Q71.1, Q72.1, Q73.1, Q74.1, Q75.1, Q76.1, Q77.1, Q78.1, Q79.1, Q80.1, Q81.1, Q82.1, Q83.1, Q84.1, Q85.1, Q86.1, Q87.1, Q88.1, Q91.1, Q92.1, Q93.1, R23.2, R24.2, R25.2, R26.2, R27.2, R28.2, R40.2, R41.2
unnamed: D1.1, Q56.3
unnamed: D2.1, Q57.3
unnamed: D3.1, Q58.3
unnamed: D4.1, Q59.3
unnamed: D5.1, Q60.3
unnamed: D6.1, Q61.3
unnamed: D7.1, Q89.3
unnamed: D8.1, Q90.3
unnamed: Q1.1, Q2.3
unnamed: Q2.1, Q3.3
unnamed: Q4.1, Q5.3
unnamed: Q5.1, Q6.3
unnamed: Q7.1, Q8.3
unnamed: Q8.1, Q9.3
unnamed: Q10.1, Q11.3
unnamed: Q11.1, Q12.3
unnamed: Q13.1, Q14.3
unnamed: Q14.1, Q15.3
unnamed: Q16.1, Q17.3
unnamed: Q17.1, Q18.3
unnamed: Q19.1, Q20.3
unnamed: Q20.1, Q21.3
unnamed: Q22.1, Q23.3
unnamed: Q23.1, Q24.3
unnamed: Q25.1, Q26.3
unnamed: Q26.1, Q27.3
unnamed: Q28.1, Q29.3
unnamed: Q29.1, Q30.3
unnamed: Q31.1, Q32.3
unnamed: Q32.1, Q33.3
unnamed: Q34.1, Q35.3
unnamed: Q36.1, Q37.3
unnamed: Q38.1, Q39.3
unnamed: Q40.1, Q41.3
unnamed: Q42.1, Q43.3
unnamed: Q44.1, Q45.3
unnamed: Q46.1, Q47.3
unnamed: Q48.1, Q49.3
unnamed: Q50.1, Q51.3
unnamed: Q52.1, Q53.3
unnamed: Q54.1, Q55.3
unnamed: Q56.1, R23.1
unnamed: Q57.1, R24.1
unnamed: Q58.1, R25.1
unnamed: Q59.1, R26.1
unnamed: Q60.1, R27.1
unnamed: Q61.1, R28.1
unnamed: Q89.1, R40.1
unnamed: Q90.1, R41.1
